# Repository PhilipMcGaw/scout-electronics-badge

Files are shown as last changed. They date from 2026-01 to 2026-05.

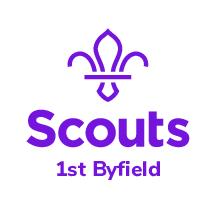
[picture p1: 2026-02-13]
KiCAD/1st Byfield.jpg

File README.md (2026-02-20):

====== Electronics badge ======

How to earn your badge:

  - Identify a number of common electronic components that are shown to you.
    - Explain, in simple terms, the functions they perform in electronic circuits.
  - Describe the systems used for marking components with their values
    - Demonstrate by identifying the values of resistors and capacitors by their markings. Explain the importance of the rating of a component.
  - Show that you know the symbols used to represent common components in circuit diagrams.
    - Show how to identify the polarity of a diode and a specific PIN on an integrated circuit.
  - Show that you’re aware of the safe working practices to be followed when handling electronic components, circuit boards and when soldering.
  - Use a multimeter to measure voltage, current and resistance in a simple circuit.
    - Explain the relationship between these values.
  - Talk about the main differences in the operation of digital and analogue circuits.
  - Construct three simple circuits.
    - One of these should be based mainly on digital electronics. They can be from a book or magazine, or you can design the circuits yourself. If possible, at least one of the circuits should be soldered using either stripboard or a custom-made printed circuit board.
  - Explain the principles behind the operation of each circuit and the typical values of voltage and current found in each.
  - Explain the possible uses of the three circuits you built.
  - Talk about the uses and benefits of electronics in everyday life.
    - Explain how electronics can be used to improve lives.

| Number  | Title                                                                                                                     | 1  | 2  | 3  | 4  | 5  | 6  | 7  | 8  | 9  | 10  |
| 1.      | Learn about resistors https://www.scouts.org.uk/activities/learn-about-resistors/                                         |    | 2  |    |    |    |    |    |    |    |     |
| 2.      | Ready https://www.scouts.org.uk/activities/ready-steady-solder/                                                           |    |    |    | 4  |    |    |    |    |    |     |
| 3.      | Multimeter multi-you https://www.scouts.org.uk/activities/multimeter-multi-you/                                           |    |    |    |    | 5  |    |    |    |    |     |
| 4.      | Thinking logically https://www.scouts.org.uk/activities/thinking-logically/                                               |    |    |    |    |    | 6  |    |    |    |     |
| 5.      | Brush bugs https://www.scouts.org.uk/activities/brush-bugs/ / https://kitronik.co.uk/blogs/resources/iet-scout-brush-bug  |    |    |    |    |    |    | 7  | 8  | 9  |     |
| 6.      | Fruit and Vegetable Power Challenge https://www.scouts.org.uk/activities/fruit-and-vegetable-power-challenge/             |    |    |    |    |    |    | 7  |    |    |     |
| 7.      | LEDs Celebrate https://www.scouts.org.uk/activities/leds-celebrate/                                                       |    |    |    |    |    |    | 7  | 8  | 9  |     |
| 8.      | Make an electric car https://www.scouts.org.uk/activities/make-an-electric-car/                                           |    |    |    |    |    |    | 7  |    |    |     |
| 9.      | Making rainbows https://www.scouts.org.uk/activities/making-rainbows/                                                     |    |    |    |    |    |    | 7  | 8  | 9  |     |
| 10.     | Power a lightbulb using potato energy https://www.scouts.org.uk/activities/power-a-lightbulb-using-potato-energy/         |    |    |    |    |    |    |    |    |    | 10  |

  * https://kitronik.co.uk/blogs/resources/scout-electronics-badge-resources
  * https://www.scouting.org/merit-badges/electronics/
  * https://cobargoscouts.org.au/jota-joti-electronics.html

  - Describe the safety precautions you must exercise when using, building, altering, or repairing electronic devices.
  - Do the following:
    - Draw a simple schematic diagram. It must show resistors, capacitors, and transistors or integrated circuits. Use the correct symbols. Label all parts.
    - Tell the purpose of each part.
  - Do the following:
    - Show the right way to solder and desolder.
    - Show how to avoid heat damage to electronic components.
    - Tell about the function of a printed circuit board. Tell what precautions should be observed when soldering printed circuit boards.
  - Do the following:
    - Discuss each of the following with your counselor:
      - How to use electronics for a control purpose.
      - Explain the basic principles of digital logic.
      - How to use electronics for three different analog applications.
    - Show how to change three decimal numbers into binary numbers and three binary numbers into decimal numbers.
    - Choose ONE of the following THREE projects. For your project, find or create a schematic diagram. To the best of your ability, explain to your counselor how the circuit you built operates.
      - A control device
      - A digital circuit
      - An analog circuit.
  - Do the following:
    - Show how to solve a simple problem involving current, voltage, and resistance using Ohm's law
    - Tell about the need for and the use of test equipment in electronics. Name three types of test equipment. Tell how they operate.
    - Demonstrate to your counsellor how to read the colored bands of a resistor to determine its resistance value.
    - Explain the differences between Through Hole and Surface Mount assembly technologies and give three advantages of each.
  - Identify three career opportunities that would use skills and knowledge in Electronics. Pick one and research the training, education, certification requirements, experience, and expenses associated with entering the field. Research the prospects for employment, starting salary, advancement opportunities and career goals associated with this career. Discuss what you learned with your counselor and whether you might be interested in this career.

  https://docs.franzininho.com.br/docs/franzininho-diy/sobre#projeto-open-hardware

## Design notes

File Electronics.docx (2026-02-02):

How to earn your badge:

1. Identify several common electronic components that are shown to you.
  a. Explain, in simple terms, the functions they perform in electronic circuits.
2. Describe the systems used for marking components with their values
  a. Demonstrate by identifying the values of resistors and capacitors by their markings. Explain the importance of the rating of a component.
3. Show that you know the symbols used to represent common components in circuit diagrams.
  a. Show how to identify the polarity of a diode and a specific PIN on an integrated circuit.
4. Show that you’re aware of the safe working practices to be followed when handling electronic components, circuit boards and when soldering.
5. Use a multimeter to measure voltage, current and resistance in a simple circuit.
  a. Explain the relationship between these values.
6. Talk about the main differences in the operation of digital and analogue circuits.
7. Construct three simple circuits.
  a. One of these should be based mainly on digital electronics. They can be from a book or magazine, or you can design the circuits yourself. If possible, at least one of the circuits should be soldered using either stripboard or a custom-made printed circuit board.
8. Explain the principles behind the operation of each circuit and the typical values of voltage and current found in each.
9. Explain the possible uses of the three circuits you built.
10. Talk about the uses and benefits of electronics in everyday life.
  a. Explain how electronics can be used to improve lives.

# History and Introduction

Electronics is the science that controls the behaviour of electrons so that some type of useful function is performed. (Electrons will be explained more fully later in this book.) Today, electronics is a fast-changing and exciting field. The rapid growth of electronics started in the early 20th century when vacuum tubes were introduced and used to manipulate electronic signals. This was something that could not be done with the telegraph and telephone circuits or the high-voltage transmitters of those days. Vacuum tubes allowed weak radio and powerful signals to be amplified, or to be made louder or stronger, and be sent on powerful waves.

Electronics changed even more dramatically in 1948 when the transistor, a small, low-powered, solid-state electronic device, was invented. Transistors are smaller than vacuum tubes, require less power to function, and are more reliable. The development of the integrated circuit, or IC, advanced this technology further. ICs can contain tens of thousands of tiny transistors built onto a small piece of conducting material. This allows for the construction and production of complex electronic circuits, which are more efficient than tubes in processing electronic signals. ICs are used in many products today, including computers, audio equipment, cell phones, appliances, and automobiles.

# How to Earn the Electronics Merit Badge

The first step in earning your Electronics merit badge is to discuss the requirements with your merit badge counsellor.

To fulfil requirement 1, learn about the precautions you should take when using, building, altering, or repairing electronic devices. Many electronic components (parts) could be damaged if mishandled. Here are some basic safety precautions; there are more safety suggestions later in this pamphlet. As you read this pamphlet and work on the requirements, pay attention to safety and see whether you can add to this list.

For requirement 2, study the chapter called “Schematic Diagrams.” You may choose a schematic diagram from this pamphlet, then copy it carefully with a pencil. Your drawing must show resistors, capacitors, and transistors or integrated circuits. Use the correct symbols for these components, label all parts, and be prepared to tell the purpose of each component. Show your drawing to your counsellor and tell what you have learned.

For requirement 3, learn how to solder and then practice soldering and desoldering wires. When you think you are ready, show your soldering skills to your counsellor. Be prepared to discuss soldering precautions, printed circuit boards, and possible heat damage to components when using a soldering iron.

Requirement 4 is demanding but fun because you will build a working electronics circuit. Choose your project carefully. Make sure that all the required parts are available at an electronics parts store, from a catalogue, or over the internet (only with your parent or guardian’s permission). Also consider what tools you will need. You can choose a project other than those in this pamphlet but check with your counselor first to make sure that the project is suitable. After you are done with the project, show it to your counselor and explain how it works.

For requirement 4 you will also learn the basic principles of digital techniques, how you can use electronics for control purposes, and about audio applications. Learn the binary system so that you know how to change decimal numbers into binary numbers and binary into decimal.

For requirement 5, you will need to solve a simple problem using Ohm’s law. You also should be able to discuss test equipment, the different types, and what they’re used for.

For the final requirement, study three career opportunities in electronics that interest you. Discuss with your counsellor the education and training needed for each.

# Tools for Electronics Work

The basic tools you will need for most of your electronics work are shown here. You can probably find some around your home and get others at an electronics parts store.

Some Basic Tools

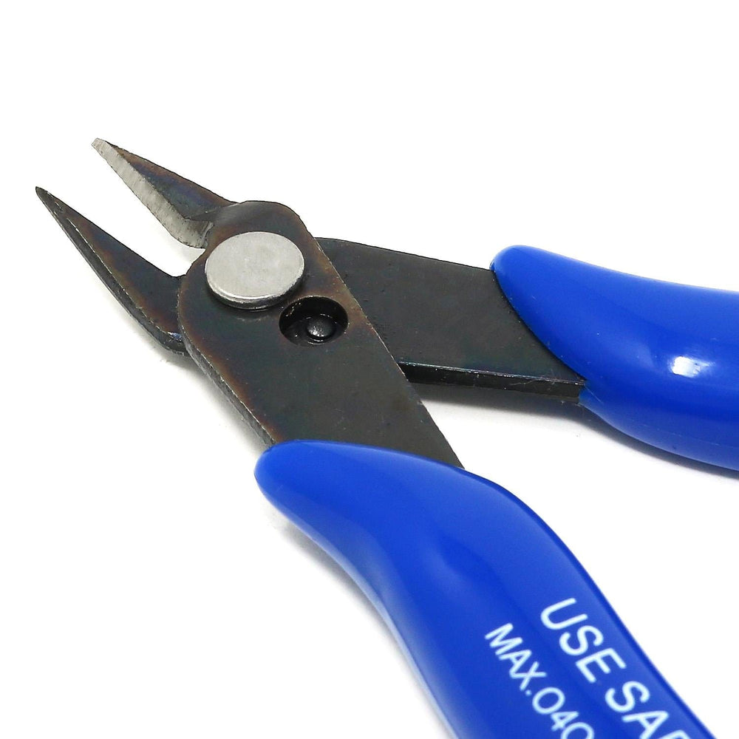
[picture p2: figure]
Precision Diagonal Cutters by The Pi Hut - The Pi Hut

https://thepihut.com/products/precision-diagonal-cutters

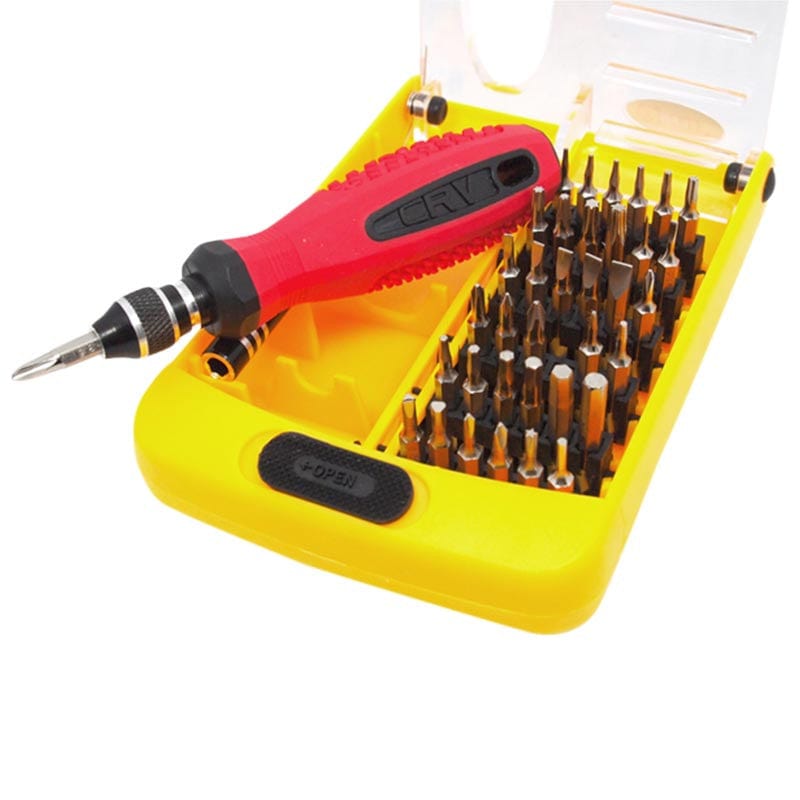
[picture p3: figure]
38 In 1 Interchangeable precise tool set by Seeed - The Pi Hut

https://thepihut.com/products/38-in-1-interchangeable-precise-tool-set

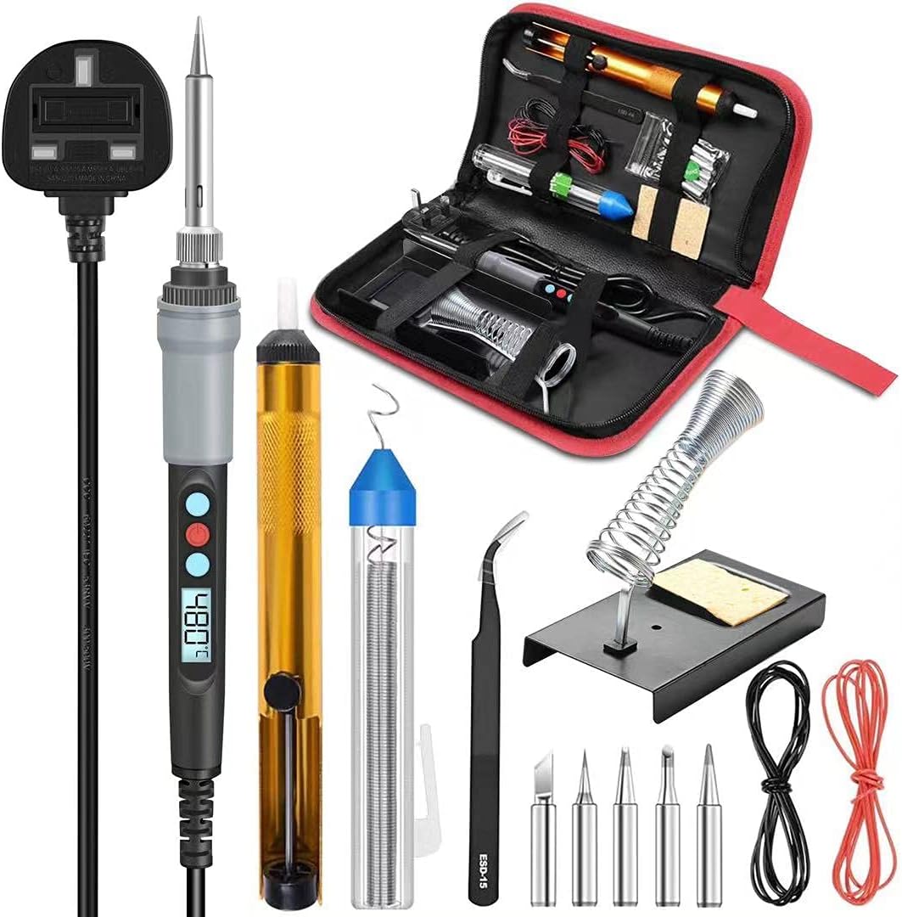
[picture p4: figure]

https://amzn.to/4a0yyuT

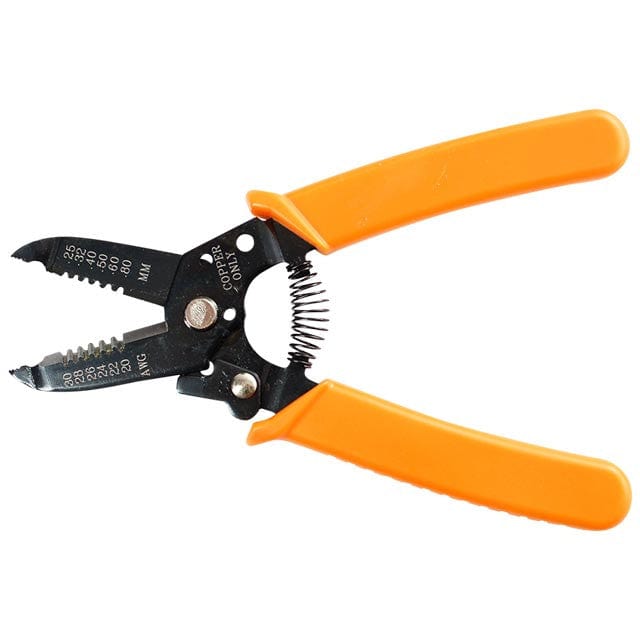
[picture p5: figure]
Multifunction Wire Strippers by The Pi Hut - The Pi Hut

https://thepihut.com/products/wire-strippers

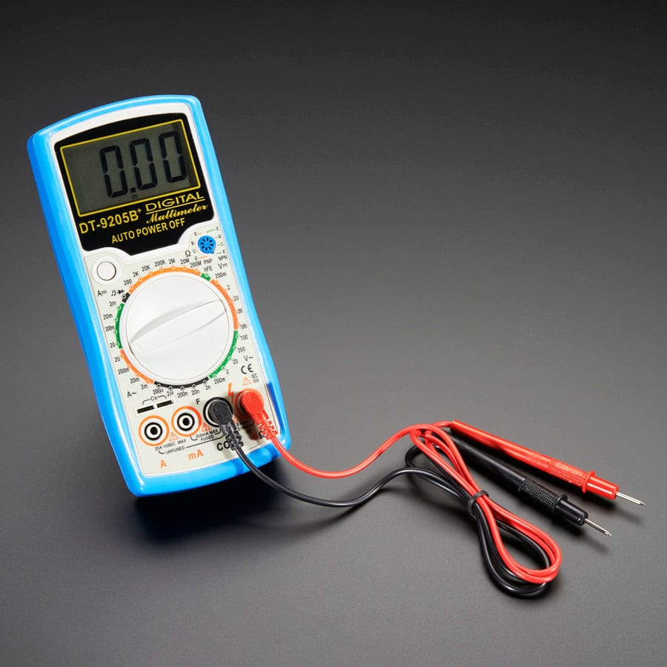
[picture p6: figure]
Digital Multimeter - Model 9205B+ by Adafruit - The Pi Hut

https://thepihut.com/products/digital-multimeter-model-9205b

For most projects, you can use any small-diameter solid or stranded hookup wire. Some projects might also require very small wire. A magnifier or magnifying work lamp is recommended for examining the circuit board to check solder connections. Most electronics parts stores have a selection of perforated circuit boards made specially for wiring electronics projects. Many come with small clips for mounting parts. These boards are ideal for building simple circuits. You also will need an electric soldering iron, which you

can buy at a hobby, electronics parts, or hardware store.

The soldering iron in a beginner’s tool kit should be a 15- to 40-watt iron with a fine chisel tip. Use a lead-free solder, like https://amzn.to/4t8N10K. Most of the solder you will need will have a diameter of 0.8 mm.

You also should have a solder wick (https://amzn.to/4bW02Ve) for desoldering a connection if you make a mistake or want to remove a component.

Use a workbench for your project if you have one. If not, you can use a kitchen table, desk, or sturdy card table. You will need to have good light and ventilation and access to power outlets. You also will need a few small boxes, trays, or jars to hold parts.

# Buying Parts

Most electronics parts stores will have the components you will need for your project. If you do a project from scratch, you will have to buy the parts separately. While you also can buy a complete project as a kit, many electronics kits found in retail stores are not soldering kits, and building a project from scratch is challenging and rewarding. Scratch projects can be inexpensive if you can scrounge for most of the parts.

However, a kit has several advantages. All the necessary assembly instructions and parts are supplied, including wire and solder. Special parts, such as printed circuit boards, come with the kit. In addition, fewer tools are required because all necessary holes are pre-drilled. Since the kit has been carefully tested, you know that the finished product will work. A complete kit generally costs less than buying the parts separately. Investigate doing a project both ways before you invest your money.

# Basic Electronics Theory

Before you learn about electronic components, let’s look at the theory behind electronics. Controlling electrons is the science of electronics. So, our study of electronics theory begins with the electron.

## Atoms and Electrons

To understand electrons, we must learn about the makeup of matter. All matter is composed of atoms, and an atom is composed of three elementary particles: electrons, protons, and neutrons. Negatively charged electrons revolve around the core (the nucleus) of the atom, which is composed of positively charged protons and neutral (not charged) neutrons.

Generally, a negatively charged electron is matched by a positively charged proton. For example, copper has 29 electrons revolving around a nucleus containing 29 protons. A basic law of nature controls electrical charges. This law simply stated is that unlike charges attract and like charges repel. This means a negative charge is drawn to a positive charge but pushes away from another negative charge. This is called electrostatic force. Normally, the positively charged protons hold the negatively charged electrons in place. However, an electron sometimes breaks away from an atom because of an outside force, such as heat, light, magnetic fields, or chemical reactions.

Once freed, electrons can “float” among atoms. These free electrons are what is important in electronics. Devices such as resistors, capacitors, inductors, and transistors are used to control the behaviour of these free electrons.

## Conductors and Insulators

Conductors act as a pathway for free electrons. Most metals are good conductors of electrons, so they can be used to “transport” electrons from one place to another. Insulators act as walls or barriers, preventing electrons from flowing where we do not want them to flow. Insulators, for example, are used on most electrical wires to protect us from electrical shock. Copper, silver, and gold are popular conductors because they have many free electrons. As an example of how to make the electrons flow, picture a length of copper wire with one end connected to the positive terminal of a battery and the other end connected to the negative terminal. The positive terminal attracts the negatively charged free electrons of the wire (remember unlike charges attract) while at the same time the negative terminal repels the electrons. The result is a flow of electrons through the wire from the negative to the positive terminal. This flow is called an electric current. An insulator works just the opposite. In some materials, such as plastics and glass, atoms hold their electrons tightly. These materials have very few free electrons. Therefore, if a length of insulator is connected to a battery the same way the copper wire was attached, no measurable current would flow.

## Current, Voltage, and Resistance

Here are some basic definitions of terms used in electronics.

- Current is the orderly movement of electrons through a conductor. Current is measured in amperes, or amps, or the rate at which electrons move past a given point. One ampere is the movement of about 6 billion billion electrons past that point in one second.
- Voltage is an electrical pressure that can cause current to flow. Voltage forces current to flow through a wire in much the same way that water pressure forces water to flow through a pipe. This electrical pressure can be caused with magnetism, chemicals, friction, light, or heat. The unit of voltage is the volt.
- The opposition to current flow is resistance. The resistance of a material is mainly determined by how many free electrons it has. If the material doesn’t have many, it will have little or no current flow. The unit of resistance is the ohm. One ohm is the amount of resistance that will allow 1 ampere of current to flow when the applied voltage is 1 volt.

## Frequency

Frequency, or cycles per second, uses the term hertz as its unit of measure. The electricity from electrical utilities is 60 Hertz AC and the voltage changes in a sine wave pattern.

## Ohm’s Law

Ohm’s law describes the basic relationships between current, voltage, and resistance. The formula for Ohm’s law is:

Voltage (volts) = Current (amperes) × Resistance (ohms)

To determine current, the formula would be:

Current (amperes) = Voltage (volts) ÷ Resistance (ohms)

If you know current and resistance, you can find out the voltage. For example, how much voltage is needed to force 2 amperes of current to flow through 10 ohms of resistance?

Ohm’s law tells us that we need to multiply our 2 amperes. (current) by the 10 ohms (resistance) to arrive at the answer: 20 volts.

If you know voltage and resistance, you can figure out current (Voltage ÷ Resistance). Therefore, how much current will flow in a circuit having 5 ohms of resistance when 15 volts are applied?

15 volts ÷ 5 ohms = 3 amperes

With these formulas, you can solve simple problems involving current, voltage, and resistance.

# Power

Another electrical quantity is power. Power is the rate at which work is done. The unit of electrical power is the watt and can be compared to the unit of mechanical power, called horsepower. One horsepower is equal to 746 watts. The formula for power is

Power (watts) = Voltage (volts) × Current (amperes)

When this formula is applied, you can determine the amount of power used by a circuit if you know the voltage and current.

For example, how much power is used by a 120-volt toaster that draws 5 amperes?

120 volts × 5 amperes = 600 watts

The power used by the toaster is 600 watts. This power is used, or dissipated, in the form of heat to toast the bread.

## Current Delivery

Electrical signals are classified as either direct current (DC) or alternating current (AC). Direct current signals are at a constant voltage or at a constant polarity where AC signals typically follow a sine wave or other pattern and alternate between positive and negative voltages. If the AC signal follows a specific pattern, the number of times the pattern repeats within one second is the signal’s frequency. The electricity from electrical utilities is 60 Hertz AC and the voltage changes in a sine wave pattern.

## Resistance and Resistors

You have learned that when you apply a voltage to the ends of a conductor, it creates a current. Its strength depends on the applied voltage and the resistance of the conductor. The resistance of a conducting material depends on three factors:

1. The kind of material
2. The length of the material
3. The diameter or thickness of the material

Temperature also is a factor in resistance. In most materials, resistance is increased when the temperature rises and decreased if the temperature is colder. In most simple circuits, however, temperature is not critical and is often ignored. The kind of material is probably the most important factor in resistance. Copper, for example, is a good conductor, while iron of a similar size has a higher resistance. Carbon has even a higher resistance than iron.

The longer the conductor, the higher the resistance will be. For instance, if the length of a copper wire is doubled, the resistance will be doubled. As an example, a 60-foot length of copper wire might have a resistance of 1 ohm. A same-sized copper wire that is 120 feet long would have a resistance of 2 ohms.

Size is important, too. A thick conductor will carry more current and offer less resistance than a thin one. Think again of water pipes. A large water pipe will allow more water to flow than a small one. When a current flows through a resistor, a component that limits or opposes the flow of a current, work is being done to move the electrons. This work produces heat and warms the resistor. Heat produced by an electric current is the basis for the operation of many electrical devices and appliances such as heaters, toasters, stoves, and soldering irons. In a lightbulb, an electrical current causes a wire filament to become so hot that it glows to produce light. Only a fraction of the power that comes from the filament produces light.

The rest generates heat, which is why incandescent bulbs are so inefficient. A resistor is designed to have a specific value of resistance, and resistors are available in a wide range of values. Standard power sizes are 1/4-watt, 1/2-watt, 1 watt, and 2 watts. These values indicate the maximum recommended power that the resistor can dissipate. The higher the power rating, the larger the resistor.

## Capacitors and Capacitance

A capacitor is a device for storing electrons, or an electrical charge, that can be released later. Imagine two sheets of aluminium foil (conducting plates) that are separated by a sheet of waxed paper (an insulator). If you connect a battery to the two aluminium sheets, electrons will flow from the sheet that is connected to the positive terminal of the battery. Simultaneously, the same number of electrons will flow from the negative terminal of the battery to the other aluminium sheet. The number of electrons that are transferred makes the voltage between the aluminium sheets exactly that of the connected battery. If the battery is removed, the aluminium sheets will remain in their charged state. If there is no leakage through the waxed paper, the sheets will remain charged indefinitely.

Any two conducting plates separated by an insulator make up a capacitor. A capacitor can consist of many conducting plates with insulating separators. Alternate plates would be connected to form interleaved stacks. The higher the voltage, the greater will be the amount of charge that is transferred from one plate to the other. The ratio of charge to voltage is defined as the capacitance of the capacitor. Or you could also say that the “electrical size” of a capacitor is its capacitance, which is the amount of electric charge it can hold. The unit of capacitance is the farad.

However, this unit is too large for most practical capacitors, so capacitors are manufactured to measure millionths of a farad (microfarads) and trillionths of a farad (picofarads, which are micro-microfarads). The insulators that separate conducting plates in a capacitor can be made of several materials, including ceramic materials, mica, certain types of paper, air, and oxide (a compound containing oxygen). A popular capacitor has been the electrolytic capacitor. In this capacitor, the insulator is an extremely thin oxide layer. The leads of electrolytic capacitors are marked positive and negative. These indicate how the capacitor must be connected for proper operation.

## Electron Tubes

The electron tube made the science of electronics possible. Although it largely has been replaced by transistors, it still has special uses. Tubes for high power are still used today in lasers, radars, strobe lights, and special-use vacuum tubes. Many high-end stereo collectors still prefer the sound of a tube amplifier over that of a transistor amplifier.

## Semiconductors

The word semiconductor is used to name a wide variety of electronic devices. Made of solid or liquid material, semi-conductors generally can conduct electricity more easily than an insulator, but not as easily as a metal. The semiconductor diode performs the same basic function as the electron-tube diode. It allows current to flow in one direction, but not the other. This diode consists of two different types of silicon crystals. An impurity (some type of substance) can be added to one area of the silicon to control the silicon’s conductivity. The silicon is said to have been “doped” when it has been treated with atoms from an impurity. These atoms combine with the silicon atoms in such a way that electrons float around freely inside the silicon. This type of silicon is called N-type (or negative-type). The N-type silicon is the cathode of the diode.

The other area of silicon also has an added impurity. But the atoms of this impurity combine with the silicon atoms in such a way that there is a shortage of one electron in the bonding. The absence of an electron is called a “hole,” and this hole can grab an electron from a neighbouring atom. Thus, a hole can “float” from atom to atom the same way an electron might. The silicon with the holes is called P-type (positive).

For current to flow through the diode, the negative terminal of the battery must connect to the N-type silicon (the cathode) and the positive terminal to the P-type silicon (the anode). The negative terminal repels the free electrons of the N-type material. The electrons are forced toward the junction where they fill the waiting holes. However, as the electrons leave the anode, new holes form. This results in a constant flow of current from cathode to anode. Current cannot flow in the opposite direction (see the illustration for the semiconductor diode). If the battery’s connection is turned around, it attracts the electrons and the holes away from the junction. Because there are no free electrons at the junction, no current can flow.

The transistor is perhaps the most important invention in the history of electronics so far. A transistor uses the P-type and N-type silicon in much the same way as a diode. However, the transistor has three electrodes, called the emitter, the base, and the collector. The collector is connected to the positive terminal of the battery, and the emitter is connected to the negative terminal. Electrons will try to flow from the emitter to the collector. However, a thin layer (the base) separates these two elements. If the base is negative, it repels the free electrons in the emitter. In this case, no current can flow from the emitter to the collector.

If the base is positive, electrons can flow into the base from the emitter. Some of the electrons will flow into the positive base lead. But because the base is very thin, most of the electrons travel through the base to the collector. Thus, if the base is made more positive, more electrons will flow. Conversely, making the base less positive will reduce the current flow. You can see then that a small voltage on the base will control the amount of current through the transistor. For this reason, the transistor can be used as an amplifier in much the same way as a vacuum tube.

Notice the symbol in the illustration used to represent the NPN transistor. Another type of transistor is called the PNP transistor. Its structure and schematic symbol are shown in the following illustration. This transistor requires opposite polarity voltages for proper operation.

NPN and PNP transistors are called bipolar transistors, and they are the most popular types used.

## Field Effect Transistor

The field effect transistor uses a single N-channel or P-channel with an insulated metal plate used to control current flow. Current enters the channel at the source lead and flows toward the drain lead at the other end of the channel. The voltage applied to the insulated plate, known as the gate, limits the current flow through the channel from source to drain. The most used FET is the metal-oxide semiconductor FET or MOSFET. An N-channel MOSFET will not conduct current if there is no voltage difference source to gate and allow current flow when a higher voltage is applied to the gate (voltage difference with respect to the source pin). A P-channel MOSFET will conduct current if there is no voltage difference source to gate and allow current flow when a lower voltage is applied to the gate (voltage difference with respect to the source pin).

Complementary MOS or CMOS technologies use one P-channel MOSFET and one N-channel MOSFET connected such that the P-channel source pin connects to the circuit higher voltage (typically power supply) and connects the N-channel source to the lower voltage supply (typically 0-volt or ground). The drain of the two MOSFETs are connected and is the circuit output. The gates are tied together. When the gates are connected to a low voltage (ground), the source to gate voltage of the N-channel is 0 volts so the channel transistor is “off” while the gate to source voltage of the P-channel FET is the “hi” voltage, so that transistor is “on” meaning the output voltage is connected to the power supply or high (for a low input). Conversely, if the two gates are tied to the higher voltage, the N-channel gate to source is now high, so it is “on” while the P-channel transistor gate to source is voltage is low, so it is “off.”

## Integrated Circuits

An integrated circuit (IC) is a complete circuit in a single package. Transistors, resistors, diodes, and capacitors can be formed in a single chip of silicon, a semiconductor. One chip can contain thousands or even millions of electronic components. Integrated circuits have revolutionized many fields, including communications, information handling, and computing. They have reduced the size of devices, while providing faster speeds and increased reliability. The individual components of ICs are extremely small and are assembled to a pattern that has been planned. A chip might look flat, but it has several layers for circuits. Switches control the electrical current through the chip. The switches manipulate the binary code (discussed below) with “on” and “off” switches. The binary code is at the core of how a computer operates.

Chips come in many different sizes, with millions of transistors being able to fit on chips the size of a postage stamp. Two basic types of IC are called linear and digital. Linear circuits include amplifiers, oscillators, regulators, and other circuits used in TV sets, audio amplifiers, radios, and hearing aids. Digital circuits include memories and arithmetic circuits and counters in watches, calculators, computers, and video games.

## Microprocessors

The microprocessor is a type of ultra-large IC. By 1971, the technique of making ICs had progressed to the point where enough computing power could be put on a single IC to form a tiny, primitive computer, or calculator. The first microprocessor was born. Today, microprocessors can incorporate more than a billion transistors, plus components such as resistors, capacitors, diodes, and wires. The microprocessor accepts input data, modifies that data in some way, and produces an appropriate output. The earliest application of the microprocessor was the calculator. A calculator accepts numbers that the user enters on a keyboard, performs a mathematical operation on those numbers that the user desires, and then sends the result to a display.

Today’s microprocessors function as the central processing unit (CPU) of computers. They also are used in many electronics systems such as cameras, printers, planes, and automobiles. The microprocessor in an automobile, for instance, examines inputs from several sensors, makes decisions based on those inputs, and adjusts such things as the mixture of air and fuel and the timing of ignition firing. The microprocessor’s most important aspect is that it can be programmed to perform an almost limitless number of applications.

## Printed Circuit Boards

A printed circuit board (PCB) consists of a sheet of some type of insulator, a composite material classified as FR-4 made of woven fiberglass cloth with an epoxy resin binder. The FR-4 material is an insulator with copper traces printed or etched onto the FR-4 surface. The copper traces are implementations of the wire lines of the schematic drawing. Parts of traces may need to be routed from one side (layer) to the other side (layer). To connect the traces, feed-through holes are added to the circuit board. Feed-through holes are drilled through the printed circuit board then filled with solder. The solder connects the copper of the top, bottom, and optional intermediate layers. Feedthrough hole’s solder is done during the fabrication of the circuit board.

Optionally, feed-through holes can be used to hold component leads. The feed through has a hole drilled through the solder for the component lead. The drilled hole is done during fabrication of the printed circuit board. The completed printed circuit board is now ready for insertion of the components drawn in the schematic.

A feed-through hole used for a component lead must be larger to allow room for the component lead diameter plus some insertion clearance of the lead into the hole. If no component lead is being inserted in the hole, the diameter of the feed-through hole can be much smaller and require less printed circuit board space. Later, during the assembly process, a component lead is inserted into the hole and the hole and lead must be soldered together to make solid electrical contact. Several layers of traces, separated by FR-4 sheets may be sandwiched together for more complex electronic designs with feed-through holes connecting the traces as needed.

## Through-Hole Technology

The technology used for placing component leads in holes drilled through the printed circuit board reached a practical limit when integrated circuits got over about 40 pins. A feed-through hole with space for the lead and the insertion tolerance meant that, based on PCB fabrication technologies at the time, integrated circuit leads needed to be about 0.100" apart. Various techniques were tried with larger IC packages including longer packages, the IC pins in a grid pattern and others. There was not a viable solution to reach what would eventually be today’s package pin counts.

## Surface-Mount Technology

By removing the component pin from going through the feed-through hole, the feed-through could be much smaller and moved away from the component. The component pins could be replaced with a square pad on the component, and the printed circuit board would have a matching pad on the “out-side” copper layer. Without the constraint of the feed-through hole with drilled lead space, component pins could be placed much closer together or more pins could be placed around the former through hole package sizes. This change led to the very high pin count packages required for today’s integrated circuits, such as the processor of your home computer.

## Schematic Diagrams

The illustrations in the previous section didn’t show you a picture of a real diode or transistor. Instead, they showed you a kind of illustrated outline, called a schematic diagram. These diagrams are a simple way of showing how electronic components are connected. In a schematic, symbols stand for the different electronic components. The schematic diagram illustrated here is for a code-practice oscillator, used to practice Morse code. The corresponding pictorial representation shows how the components look. In the schematic, a different type of symbol represents each type of component:

long and short lines represent the battery; a zigzag line stands for a resistor. In this section, you will learn these symbols so that you can understand schematic diagrams.

To start, compare the schematic diagram with the pictorial and match each symbol in the schematic with its equivalent component in the pictorial. Also match each line in the schematic with the appropriate wire in the pictorial. Notice where two lines cross in the schematic. If the wires are to be connected, a dot shows at the crossing on the schematic. If there is no dot, the two wires bypass each other and are not connected.

When you draw your schematic for requirement 2, you will need a sharp pencil, paper, and a ruler or straight edge for drawing straight lines. A compass might be helpful for drawing circles. If you have a computer with a drawing program, you might use that to draw a schematic. There are also several freely available schematic capture tools.

# Component Types

Before we look at the most common types of electronics components, as well as the schematic symbol and a pictorial of each one, let’s define and review some basic terms (also see the Basic Electronics Theory section):

- Electricity is a property that electrons have that causes them to behave in certain predictable ways.
- Electrical charge is a quantity of electricity.
- The electron is a tiny particle that has a negative electrical charge.
- Current is defined as the flow of electrons.
- Voltage is the pressure that causes current to flow.
- Resistance is the opposition to current flow.
- Direct current (DC) is current that always flows in the same direction.
- Alternating current (AC) is a current that reverses its direction of flow many times each second.
- Frequency is the number of times that a repeat its pattern in one second.

## Passive Components

### Fixed Resistor

Each resistor has a specific amount of resistance. A resistor is like a nozzle on a water hose. For a given water pressure, the nozzle controls the amount of water that is allowed out of the hose. Similarly, for a given voltage, a resistor controls the flow of electrical current.

Most resistors are made of a carbon compound. Resistors used for high currents often are made from special wire that is wound on an insulating form. The type of compound or wire used determines how much electrical current can flow for a given voltage. The value of a resistor is given in ohms. The symbol for the ohm is the Greek capital letter omega (Ω). Thus, 1Ω designates the resistance of 1 ohm. A 1kΩ resistor has a resistance of 1 kilohm, or 1,000 ohms. A 1MΩ resistor has a resistance of 1 megohm, or 1 million ohms.

The illustration below shows a variety of fixed resistors and a cross-section of a fixed resistor. The values of fixed resistors cannot be changed.

Older types of fixed resistors have bands of colour that allow you to determine their resistance value. (See “The Colour Code of Resistors” section on page 40.) The cross-section of this fixed resistor shows the inside, which is made of carbon.

Note the schematic symbol for a fixed resistor.

### Variable Resistor

The resistance of variable resistors can be adjusted. Rheostats are two-leaded devices that vary in resistance from 0 to the rated resistance value. Three leaded variable resistors, known as potentiometers (pots), have a fixed resistance between leads 1 and 3, and have a resistance on lead 2 proportional to the amount of rotation on the adjustment arm. These variable resistors can be used in appliances that need their currents adjusted or when the resistance needs to be varied, such as with lights that can be dimmed.

### Capacitor

A capacitor is a storage element for electrical charge, like a bottle that stores a liquid. The basic unit of capacitance is the farad (F). Practical capacitors have capacitance values in microfarads (µF). The physical size of a capacitor depends on its voltage rating and its capacitance value. The higher the voltage rating and the larger the capacitance value, the larger the capacitor must be.

### Inductor

An inductor is a coil of wire usually wrapped around some type of metal or hollow core material and is used to smooth out variations in the current flow. When current is applied to the coil, a magnetic field is established around the core. When the current flow stops, the magnetic field begins to collapse and in doing so induces current back into the wire until the field has collapsed. The magnetic field tends to collapse at a rate that maintains the original current in the wire. Single coil configurations are generally called a choke whereas two or more coils can be configured either as a choke to filter current changes or as a transformer for changing voltage and current values.

### Transformer

A transformer consists of two or more coils each with multiple turns of wire around the magnetic core. The primary coil is the coil where power is applied to the transformer and the other coils are referred to as secondary coil(s). The transformer uses the magnetic field established by current flow in the primary coil to induce a current in the secondary coil(s). The ratio of turns from the primary to a secondary coil determines how much the incoming voltage is multiplied on the secondary side and how much the secondary current is divided by the primary current in the secondary. Because transformers operate on changing magnetic fields caused by changing current, transformers do not operate on direct current (DC) currents.

## Semiconductor Devices

Semiconductor devices are typically made of silicon-based material. Diodes and transistors are two common semiconductor component types. Semiconductors come in various package sizes based on the amount of power they must dissipate in rated operation.

### Diodes

Diodes operate as check valves, passing current in one direction but not the other. A diode’s most common application is in power supplies. It changes alternating current (AC) into direct current (DC).

### Transistors

Transistors are solid-state devices used for controlling current. A very small input current controls a much larger output current. For example, the small current from a microphone can control a much larger current that drives a loudspeaker. This is the idea behind the audio amplifiers used in public address systems.

### Integrated Circuits (ICs)

Complex circuits are available in integrated circuit (IC) form at inexpensive prices. The IC, which typically consumes little power, is reliable, cheap, and small. Because devices using ICs can be improved and made cheaper, the IC has replaced traditional components in many applications. As shown here, ICs come in several types of packages. The dual in-line package (DIP) is the most popular style for most hobby applications.

Schematic symbols for ICs are typically very function specific.

## Electromechanical Components

### Microphone:

A microphone changes sounds into electrical impulses. Either a thin, flexible disk (a diaphragm) or a crystal in the mike vibrates whenever sound strikes it. The vibrations are changed into small electrical signals. These signals typically need to be amplified before they are usable.

### Speaker

A speaker then converts the electrical impulses back into sounds. An electromagnet moves a speaker cone based on the incoming audio signal. The speaker cone moves the air around and it which causes the audio sound to spread across the space and recreating the original sound.

### Switches

Switches are an important part of almost all electronic equipment. They come in a wide variety of shapes, sizes, and functions. Switches are categorized by the number of circuits they switch (single, double, triple, etc.) and then by the number of switch position contacts. A switch may have an output contact for each position of the switch. The switch will typically have a default position. A circuit that makes contact in that position is called a Normally Closed (NC) contact or in drawing below from terminal A to C. If the switch is moved out of default position, and contacts an electrical terminal, that position is called Normally Open (NO) and is shown as connections A to B in drawings below).

The simplest is the single-pole, single-throw type. When closed, this switch completes a circuit, allowing an electric current to flow. When it is open, the circuit is broken, and the current does not flow. The on-off switches on most electronic devices are of this type (above left).

A single-pole, double-throw switch has a contact arm that can be set in either of two positions. In the example shown here, terminal A can be connected to either terminal B or terminal C. The dashed line between the switches shows the mechanical connection (above centre).

A double-pole, double-throw switch can simultaneously switch two wires from one circuit to another. It can be thought of as two single-pole, double-throw switches that operate together (above right).

A rotary or selector switch has one or more arms (poles) that can be set to various positions. A single pole 10-position switch is shown below. Notice that the terminal at the very bottom connects the signal to the rotatable arm.

### Relays

A relay is a magnetically operated switch. It has a wire coil wrapped around an iron core forming an electromagnet. When current flows through the coil, a magnetic field develops. The magnetic field attracts a movable part called an armature, which moves all relay switch poles from normally Closed (magnet off) to Normally Open (magnet energized).

A relatively small current can cause the switch contacts to close, but the contacts can handle a much heavier current. The relay allows a small current to switch higher current(s) on or off. By using several contact sets (single, double, triple or more poles and single or double throw). A multi-pole relay allows a single control (coil) current to control several different currents simultaneously.

## Chemical Components

### Batteries

Batteries are made from several types of materials for different uses. Alkaline, lithium, and mercury batteries are used when long life is desired. Nickel-cadmium batteries give shorter service but can be recharged. The nickel–metal hydride battery is replacing the nickel-cadmium battery because it doesn’t suffer the memory effect (that is, not allowing a partially charged battery to fully recharge before use). Lithium-Ion type batteries have replaced many of the older battery types. Zinc-carbon also is used in many inexpensive dry-cell batteries. Most electronic circuits and products operate at low supply voltages and have low power requirements. These devices are often driven from small batteries or DC voltage sources. Depending on the type of product, a coin battery, one, two or four flashlight batteries are often adequate for relatively long service.

Ordinary flashlight dry cells produce approximately 1.5 volts. Four 1.5-volt cells connected in a series can provide 6 volts. Single 9-volt batteries also are used.

### Photocells

A photoelectrical cell changes one or more of its characteristics when exposed to light. It is popularly called the electric eye, which controls operations such as traffic lights, door openers, and devices that activate lights at dusk and turn them off at dawn. One type of photoelectric cell is called a photoconductive cell. Another name for this type of cell is the light-dependent resistor (LDR). This special resistor has a small window so that light can strike the resistance material. Generally, such a cell has a high resistance when in darkness. Another type is called a photovoltaic cell. This is the familiar “solar cell” that is used to power electronic equipment on spacecraft. It produces a low voltage across its terminals when exposed to light, especially sunlight, thus converting light energy into electrical energy.

## Other Component Types

There are many other types of components used in electronics, but these are the more common components that a hobbyist is likely to use.

# The Colour Code of Resistors

The value of a resistor is specified in ohms and is indicated by coloured bands around one end of the resistor. The electronics industry devised this system because small, printed numbers would be too hard to read or might be concealed by the position of the resistor.

Most resistors have four bands, with the first three (counting from the end of the resistor) indicating the value in ohms. The fourth, which is either silver or gold, indicates the tolerance (discussed below). colours used for the bands are used in place of numbers. To determine the resistance value in ohms, examine the colour bands starting with the one closest to the end of the resistor.

Suppose a resistor has a brown, a black, and then a brown band. The code chart shown here tells you that brown represents the number 1. The second black band represents the number 0. The third band tells you how many zeroes to add to the first two numbers. In the example, the band is brown, so you add one zero. Therefore, the value of this resistor is 1-0-0, or 100 ohms.

Now try the example for the resistor shown here, which has a red band first, then a yellow band, and then an orange band. The red band means that the first number is 2. The yellow band corresponds to the number 4. The orange band tells us to add three zeroes. Thus, the value is 2-4-000, which translates to 24,000 ohms, or 24 kilohms (kΩ).

Most surface mount components are too small for colour bands, so the colour bands are converted back to digits and printed onto the top of the resistor as 243 for 24,000 ohms, or 24 kilohms (kΩ).

# Soldering

Before you begin working with a circuit, read and study this chapter on soldering. Anyone working in electronics must know how to solder well, and safely. It takes practice, but once you learn, you will be able to properly assemble an electronics project. In all electronics work, the wiring connections must be secure. A loose connection in a radio, for example, could result in noise, scratching sounds, or no sounds at all. Poor connections in a TV could disrupt the sound and picture. And beyond just a radio and a TV in someone’s home, the safe operation of airplanes and the lives of astronauts in flight depend on secure electronics connections.

Soldering is not just gluing metals together like you glue together pieces of wood. Done correctly, soldering unites the metals so that electrically they act as one piece of metal. You do this with a mixture of lead and tin solder and a soldering iron.

## The Soldering Iron

An inexpensive pencil-type soldering iron of no more than 40-watt capacity (15 to 25 watts are also suitable) is the best for electronics work. The tip should be 1 to 2 mm; the solder should be 1 mm. It is helpful to get an iron with interchangeable tips of different diameters or shapes to be used on different kinds of work. The iron should be well-balanced and have a handle that will remain cool while you work. Tinning your iron means coating the tip of the solder iron with a thin coat of solder. If your iron is new, read the instructions about preparing it for use. Most new irons are already tinned, so you might not have to tin it. If the tips are silvery, you can use them as they are. If instructions aren’t included with your iron and the tip is not silvery, first use a fine file to file the tip until it is shiny. Then heat the iron and coat the tip with rosin-core solder. Be sure to coat all sides of the tip.

If you have an older iron that has been used and the point is already silvery, just wipe it clean with a cloth, and you are ready for work. If it is dull or looks coppery, file and tin it. You also should have a heat-resistant bench-type iron holder so that the hot iron can safely be set down between uses. Look for one that has a holder for tip-cleaning sponges.

## How to Solder

A well-soldered joint, one that will be reliable in use, will be nice and shiny looking. To achieve a well-soldered joint, make sure you do the following:

1. Solder with a clean, well-tinned tip. Wipe the tip on a damp sponge before soldering and between soldering.
2. Make sure all wires, parts, and the circuit board to be soldered are clean.
3. Make a good mechanical joint before soldering.
4. Allow the joint to get hot enough before applying solder, then apply an adequate amount of solder to the joint. Only heat the joint with the solder iron, not the solder itself. When you touch the solder to the joint, the solder will flow onto the joint
5. Allow the solder to set before handling or moving soldered parts.

Remember that in preparing work for soldering, dirt is the enemy of soldering. A solder will not take if parts are dirty, so be sure to completely clean all wires and surfaces before applying solder. Use fine sandpaper or emery paper to clean flat surfaces or wire. If you do have dirty parts or a dirty surface, you might try to use too much heat to force a connection. When preparing wires, remove the insulation with wire strippers or a hobby knife. If using a knife, hold the knife at an angle as if you were sharpening a pencil. Do not cut straight into the insulation because you could nick the wire and weaken it. For enamelled wire, use the back of the knife blade to scrape the wire until it is clean and bright.

Next, tin the clean end of the wire. Hold the heated tip of the soldering iron against the undersurface of the wire and place the end of the rosin-core solder against the upper surface. As the solder melts, it will flow on to the clean end of the wire. Hold the hot tip of the iron against the under surface of the tinned wire and remove the excess solder by letting it flow down the tip. When properly tinned, the exposed surface of the wire should be covered with a thin, even coating of solder.

Unless you are creating a temporary joint, the next step is to make a good mechanical connection between the parts to be soldered. For instance, wrap the wire carefully and tightly around a soldering terminal or soldering lug. (Bend wire and make connections using long-nosed pliers.) When connecting two wires, make a tight splice before soldering. Once you have made a good mechanical contact, you are ready to solder.

When you are working with an ordinary circuit board, you will bend the wires of a component through the board. For those parts, such as some resistors, that become hot when in operation, raise them slightly above the board to allow some air circulation. The next step is to apply the soldering iron and solder to the connection. The temperature of all the parts that are being soldered should be raised to about the same degree before applying the solder. If soldering a spliced wire, hold the iron below the splice and apply solder to the top of the splice. If the tip of the iron has a bit of melted solder on the side held against the splice, heat is transferred more readily to the splice, and the soldering can be done more easily. Don’t try to solder by applying solder to the joint and then pressing down on it with the iron.

It usually takes two to three seconds to solder on a printed circuit board. Remember: Too much solder on a joint might cause short circuits with adjacent joints. However, if you don’t apply enough solder, you might not form a secure and fully working joint. When soldering the wires of a component, you might snip the extra wire leads off before soldering. However, with some components, such as semiconductors, it might be best to snip the surplus wire after you have made the joint.

Don’t disturb the soldered joint until the solder has set. This might take several seconds, depending on the amount of solder used to make the joint Then take a good look at the joint. It should have a shiny, smooth appearance. It should not be pitted or grainy. If it is, then reheat the joint, scrape off the solder, clean the connection and start over.

After the solder is well set, pull slightly on the wire to see whether it is a good, tight connection.

## How to Desolder

In case you accidentally make a wrong connection or must move a component that has been placed incorrectly, you should learn how to desolder connections. Take care when desoldering to avoid breaking or destroying good parts. The leads on components such as resistors or transistors and the lugs on other parts might sometimes break off when desoldering a good, tight joint. To avoid heat damage, use as much care in desoldering delicate parts as you do in soldering them.

There are two ways to desolder. The first and usually easiest way is to use a metal wick or braid on a small dispenser reel to remove the melted solder. This braid is available at most electronics parts’ stores. Place the braid against the joint that you want to desolder. Use your heated soldering iron to gently press the braid against the joint. As the solder melts, it is pulled into the braid. Don’t let the joint cool while the braid is resting against the joint. By repeating this process, you can remove virtually all the solder from the joint. Then reheat the joint and lift off the component leads.

The second method involves using a desoldering pump, or a vacuum device, to suck up the molten solder. Most electronics parts stores have these devices. Follow the manufacturer’s instructions for the pump you are using, but here are some general guidelines. Use your soldering iron to heat the joint you want to desolder until the solder melts.

Then push down on the top of the pump to remove the air inside. Next, quickly place the tip of the pump on the melted solder you want to remove and press the button on the side. This will cause the pump’s plunger to rise rapidly and create a vacuum inside. The rush of air at the tip of the pump will pull the melted solder in. Repeat until you have removed most of the molten solder. Then reheat the joint and gently pry off the wires. Experiment with and practice your soldering techniques to fulfill requirement 3 before you begin working on your circuit. Use pieces of wire or some old components and wire. Practice until you can solder joints that are smooth, shiny, and tight. Then practice desoldering some of the connections until you are satisfied that you can do them quickly and without breaking wires or lugs.

## Soldering Printed Circuit Boards

Most electronic devices use one or more printed circuit (PC) boards. A PC board is made of a nonconducting material, such as a thin sheet of fiberglass or phenolic resin (plastic) that has a pattern of foil conductors “printed” on it and has predrilled holes designed to hold components. You insert component leads into the holes and solder the leads to the foil pattern. This method of assembly is widely used, and you probably will use it if you choose to work with an electronics kit. Printed circuit boards make assembly easier. First, insert component leads through the correct holes in the board. Mount the parts tightly against the circuit board unless otherwise directed. Insert a lead and then bend it slightly outward to hold the part in place. Then follow these steps.

1. Touch the tip of your soldering iron to both the component lead and the foil until they are uniformly hot enough to melt the solder.
2. Apply a small amount of solder to both the tip and the connection.
3. Remove the iron and let the solder set before moving the wire or the board. The finished connection, as you have learned, should be smooth and shiny.
4. Finally, clip off the excess wire length.

Occasionally a solder “bridge” will form when solder connects between two adjacent foil conductors. You must remove such bridges, or a short circuit will exist between the two conductors, and the circuit won’t function properly. Remove the bridge by heating it with your soldering iron and quickly wiping away the melted solder with a soft cloth.

# Control Devices

An important application of electronics is the control of certain operations with the use of control devices. For example, control devices can make lights go on at certain times or open doors automatically. To satisfy requirement 4, you will build a working electronic circuit. You may choose to build a control device.

## Building a Control Device from Scratch

You can build a control project from a kit, but you may want to build a project from scratch. The one shown is easy to build and fun to use. It is a control circuit that uses light to control an audible alarm. This is a popular type of control circuit. It could be used to detect when the sun is shining so you can turn out your lights and save power.

The circuit is constructed on the single piece of 3-by-4-inch perforated board. While the exact size is not critical, a board that is too big is better than one that is too small. The holes in the board need to be 1/10 inch apart. This is necessary so that the pins of the op amp will fit.

Many types of boards are available. The board used (and shown in the photographs) for this project has foil patterns designed especially for integrated circuits, which makes the project easier. To use this type of board, insert components through the board from the top and solder to the foil patterns on the bottom of the board. You make connections from one component to the next by using short wires called jumpers.

## Procedure

To build this circuit, follow these steps.

Step 1—Gather the parts. You may be able to buy parts at an electronics supply store, but more easily today you can purchase electronic components online (see the resources section at the back of this book). It’s a good idea to make sure you can find all the parts before you buy any of them. This circuit will work with a wide variety of parts.

Step 2—Lay out the circuit board. Before you begin, decide where each component will go on the board. The illustration here shows a suggested layout. Lay the components on the board and trace the outline of each to make sure everything will fit properly.

Step 3—Drill the holes. You must drill several holes (see the illustration for the pattern) in the circuit board before mounting any components. The four holes at the outer corners are for the four standoffs, or legs, that will hold the circuit board. It is recommended that you buy a board that has these four holes already drilled. This will leave you with only three holes to drill. The first is the small hole for the battery holder. Make this hole slightly larger than the screw that holds the battery holder to the board. Two larger holes are required for the potentiometer and the switch. In each case, make the hole slightly larger than the part that is to be inserted through it. Drill the holes carefully so you don’t damage the perforated board.

Step 4—Mount the IC. Attach the 741 op-amp first. It must be mounted so that its pins are attached to foil patterns that allow additional components to be attached. Insert the IC in the top of the board.

Identify pin 1 of the 741 Op amp IC as illustrated on the top of the next page. Mark pin 1 on the board with a pencil so that it is easier to identify each of the pins as you solder components to them.

Step 5—Mount the LDR. Insert the leads of the light-dependent resistor into the board at the location shown and solder the leads to the foil. Don’t worry about which lead is which. The LDR can be turned either way.

Step 6—Mount R2, R3, and R4. Insert the leads of the resistors at the locations shown. Bend the leads over so that you can insert them through the board and solder them to the bottom side. Don’t worry about which lead is which. The resistors can be turned either way.

Step 7—Mount the transistor.

Insert the transistor (Q1) into the board, carefully observing the emitter, base, and collector connections. The drawing illustrating the 2N3053 transistor seen at the bottom of the page shows how to identify the three elements.

Step 8—Mount the buzzer. Insert the buzzer (PB) through the board. Note that the minus (–) and plus (+) sides must be connected as shown in the schematic.

Step 9—Mount the switch. First remove the retaining nut. Mount the switch by pushing it through from the bottom of the board. Attach it to the board with the retaining nut. Cut two lengths of wire, each about 3 inches long. Remove 1/4 inch of the insulation from each end of the wire. Turn the board upside down and connect the centre switch post to a foil pattern using a prepared wire and one of the side of the switch posts to another foil pattern using the other wire.

Step 10—Mount the potentiometer. Remove the retaining nut. Mount the potentiometer (R1) by pushing it through from the bottom of the board. Attach it to the board with the retaining nut. Cut three lengths of wire, each about 3 inches long. Remove 1/4 inch of insulation from each end of the wire. Turn the board upside down and connect the potentiometer lugs to the foil patterns by using the three prepared wires as seen in the top view shown here.

Step 11—Mount the battery holder.

Step 12—Mount the battery clip. Strip 1/4 inch of insulation from the ends of the battery clip’s black and red leads. Solder the black and red leads to the board. Do not connect the battery yet.

Step 13—Interconnect each of the components using small jumper wires, being sure each wire is electrically connected between the correct components. A good way to do this is to refer to the schematic and colour each line on the schematic as you connect that jumper wire on the board. Cut each wire to the length needed and remove 1/4 inch of insulation from each end of the wire. Insert the jumper from the top of the board and solder to the foil on the bottom.

Step 14—Check all wiring. Before you apply power, recheck all wiring as described in the soldering section. Make certain that all components are interconnected properly. Check the pins of the op amp to make certain that you have the pin numbers right. Also recheck the placement of the transistor (Q1).

Step 15—Apply power. Attach the battery clip to the battery. If the buzzer sounds, flip the on-off switch to the opposite position. Place the battery in the holder.

Step 16—Coarse-adjust R1. Flip the on-off switch to the “on” position. If the buzzer does not sound, adjust the potentiometer until you hear a sound from the buzzer. If you cannot make the buzzer sound by turning the potentiometer, flip the switch in the “off” position and adjust the potentiometer until the buzzer sounds. If the buzzer will not sound in either switch position, then immediately disconnect the battery and recheck all wiring. Correct the problem by rewiring as necessary. Repeat the process until you hear a tone from the buzzer.

Step 17—Fine-adjust R1. Once you get a sound from the buzzer, cover the LDR with a finger to block light from the device. With the LDR covered, back off the setting of the potentiometer just to the point where the buzzer no longer sounds. The buzzer should now sound when the LDR is uncovered but stop buzzing when the LDR is covered. The circuit is detecting the presence of light and responding by sounding the buzzer.

## Circuit Operation

To understand how the circuit works, refer to the schematic diagram shown on the previous page. Start at the buzzer (PB) and work backward. The buzzer will sound when current flows through it. Transistor Q1 controls the current through the buzzer. When Q1 conducts, current flows through Q1 and the buzzer, creating the sound. In turn, the 741 op amp controls Q1. The 741 (IC1) is an integrated circuit that contains dozens of transistors connected as a very high-gain amplifier. This means that it can amplify extremely tiny differences in the voltages applied to the two input terminals (pins 2 and 3).

The resistance of the light-dependent resistor (LDR) determines the voltage on pin 3 of the op amp. If no light strikes the LDR, the resistance across the LDR is high, which causes the voltage at pin 3 of the op amp to be low. When light hits the LDR, its resistance falls and the voltage on pin 3 of the op amp increases.

Before using the circuit, in steps 16 and 17, you adjusted the setting of R1. Moving the arm of R1 changes the voltage at pin 2 of the op amp. With the LDR shielded from light, you set R1 just below the point at which the buzzer is activated. When R1 is properly set, the voltage at pin 3 is slightly lower than the voltage at pin 2. The op amp amplifies this tiny difference in voltage and produces a very low voltage at its output. This low output voltage holds Q1 cut off so that no current can flow through the buzzer.

When light hits the LDR, as was noted, its resistance drops. This increases the voltage at pin 3 of the op amp. The op amp amplifies this difference, producing a high voltage at its output. This turns Q1 on, forcing current through the buzzer and sounding the alarm.

# Digital Electronics

Since the use of transistors began in 1948, the field of electronics has undergone a revolution that continues to allow for the introduction of a vast array of new devices. The development of digital electronic components has revolutionized fields such as computing, communications, and information handling. Such components have replaced many traditional circuits and components.

Possibly the best example of this revolution is the personal computer and related products. Other examples are digital watches, digital thermometers, hand-held computers and games, complex calculators, electronic games, televisions, and digitally recorded music and videos.

## Binary Number System

To understand digital electronics, you must first learn the binary number system, which is used in digital equipment.

The decimal system of numbering uses 10 different digits: 0, 1, 2, 3, 4, 5, 6, 7, 8, and 9. This number system is suitable for people but is too complex to be used by electronic circuits. Digital logic is a simple process that can make only two decisions: true or false. So, the binary number system has only two digits: 0 and 1. Thus, “true” can be presented by 1 and “false” by 0.

With only two digits, how are numbers larger than 1 represented? The answer is the same way numbers greater than 9 are represented in the decimal system. In the decimal system, the highest single-digit number is 9. We represent numbers greater than this by using two or more digits in combination. That is, 10 is represented by using the digits 1 and 0 together.

In the binary system, the highest single-digit number is 1. To represent numbers greater than this, we again use two or more digits in combination. The number 2 cannot be represented by the symbol “2” because this digit is not used in the binary system. Instead, the digits 1 and 0 must be used together, to form 10. Therefore, in the binary system, 10 represents the number 2 and not the number “ten.” The number 3 is represented by the next larger two-digit number of 11.

Now, how do we represent the number 4 in binary? Since we no longer have two-digit possibilities, we must use a three-digit number. The lowest three-digit number is 100. In the decimal system, this means “one hundred.” In the binary system, 100 means “four.”

Here is a chart showing decimal numbers up to 17 and how to represent them using the binary system. Study this table to help you understand the binary sequence. Then try to continue the list to 32 (decimal), or 100000 (binary).

Charly Plexing

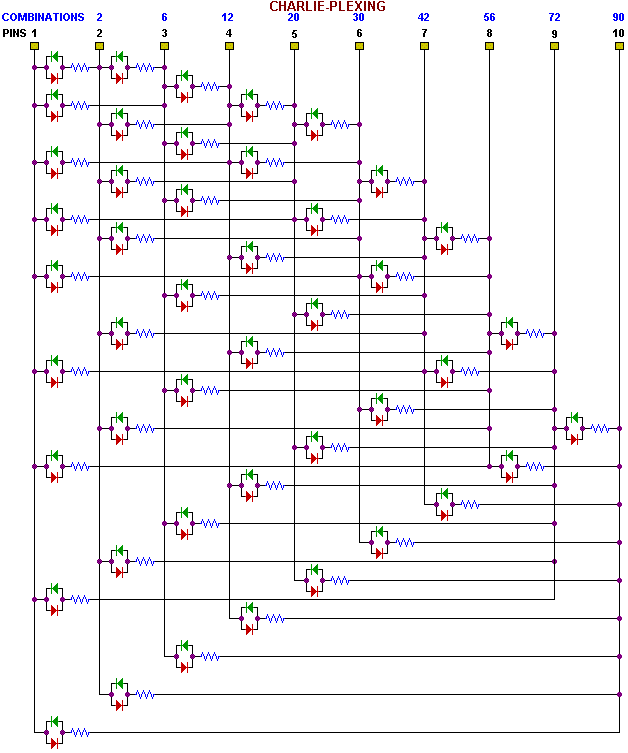
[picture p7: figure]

# Woggle

This is derived from the Scouts Queensland eWoggle, and follows the design principles laid out in the document “Circuit design principles for Scout electronics projects for JOTA/JOTI“ by Michael Gross of Cobargo Venturers (https://cobargoscouts.org.au/jota-joti-electronics.html), I have also combined the functionality of the eWoggle with the Franzininho DIY (https://docs.franzininho.com.br/docs/franzininho-diy/sobre) Arduino like capabilities allowing the scouts to upload new firmware after they have assembled their woggles.

## Woggle KiCad files

The woggle was designed in KiCad,

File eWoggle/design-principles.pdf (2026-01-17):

# Circuit design principles for Scout electronics projects for JOTA/JOTI

## Aim

- To make simple circuits from discrete components and single function integrated circuits, so that Scouts can learn that the circuits are just composed of simple building blocks that can be easily understood.
- Design circuits that are both useful and appealing to the youth members
- Circuits must be able to withstand the assembly, and subsequent handling. (it must be tough)

## Issues

- Soldering and assembly Skills of youth members learning to solder can be rather “harsh” on PCB’s. 10-20% failure is not uncommon.
- Some components can be fragile. (physical weakness and static issues)
- Commercially available kits tend to have the battery, Speaker, switches and other components separate from the PCB - the end result is that the leads tend to be broken off speakers and batteries easily.

## PCB Design principles

1. All components must be mounted on 1 board - e.g speaker, battery etc.
2. Use only most commonly available components
3. Special components that have limited availability, must have different options available, and the board must be designed to accept a number of alternatives if these are not available.
4. Circuits should use as little power as possible to extend battery life.

## PCB Design

1. IC’s - all mounted on sockets - iC’s only inserted after soldering is checked, also ensures that IC’s are not damaged though too much heat or static.
2. Battery holders - PCB mounted, but also attached by double sided tape to take the strain off the pins. Must be able to take different pin spacing from different manufacturers. Also be able to take a battery holder with wires (separate holes for this if necessary)
3. Speakers - PCB mount preferable - encased with pins, or bare speaker with leads. provision must be made to take different size speakers with different mountings. Attachment, solder in, or stick on (small mylar speakers tend to have a protruding ring that makes it easy to stick them on), also provision for screw holes, or even cable tie attachment.
4. On/Off Switches - preferable to Scouts just removing the battery. Switches must be anchored to the board by their casing as well as their leads if possible. Cases must be 1 piece, not spot welded together, so they do not break apart. Switch toggle must not extend past the board boundary, so there is less risk of it breaking off.
Michael Gross - Cobargo Venturers | V1, 11th July 2020 | Page - 1

Momentary switches are preferable, so that circuits do not accidentally get left on and drain the battery. If Momentary switches are not suitable, then a power on led should be used as indication that the power has not been turned off.

5. Silk Screen - Front of PCB - component labelling, orientation “+ and -“, component outline, all special solder pads labelled - eg battery pcb mount, battery wire mount.
6. Silk Screen - Back of PCB - Large white space for Scouts name and group name. Revision number, circuit name
7. Lanyard attachment hole (5mm) - at the top of the board
8. Larger solder pads (2.5 to 3mm) - to better handle heat dissipation from excessive solder and extended heating times, and make it easier to solder.
9. Wider tracks (min 0.75mm) - in case pads are delaminated (common), so that component leads can be bent over solder mask scraped away and lead soldered to the remaining track - saves replacing the whole board and starting again.
10. Track Layout - last section of track to plated through holes is always on the solder side so that if a component completely covers the holes (eg pcb mount speaker or battery holder), and the pad is delaminated, the pin can still be connected to the track (see step 9).
11. Pin spacing - leave enough space between component ends and through holes so that the leads are not bent close to the component, this also allows for different value components - eg ½w if ¼ w resistors are not available
12. Room for components - ensure that all components have enough room around them to make assembly easy.
13. Axial leads components where possible as there is more spacing between pins on the board - so less likelihood of bridging holes.
14. Switches - connect all pins if they have connection to other pins, so if a track is delaminated then the switch will still work.
15. Only one track to pad connection, so that if a pad is delaminated then only one join has to be made
Michael Gross - Cobargo Venturers | V1, 11th July 2020 | Page - 2

If the middle pad is delaminated then you need to make 2 connections - not preferable

If the middle pad is delaminated then you need to make only 1 connection - much easier to fix.

Layout summary

Pad sizes
1. Oversize pads - set to min 3 mm round on axial components
2. if pads close together then 2.5mm* 3 mm oval or round shape
3. Ic pads 2.5mm x 1.5mm oval

Track sizes and layout
1. 0.75mm tracks - to handle heat dissipation better, and allow for easy lead connection if pad is delaminated
2. Move tracks as far away from other holes as possible
3. Last section of track to through hole to be on component side.
4. 1 track to 1 pad, T join tracks instead, so that if a pad is delaminated there is only 1 connection to make.

Customisable Screen print suggestions
1. Scouts State Logo
2. Region Logo - if available)
3. Scout Group - name
4. Group website URL
5. Event details - JOTA/Jamborette and year if applicable
6. On Back - large white space for Name and also for Group/section

Contact - Venturers@cobargoscouts.org.au

Michael Gross - Cobargo Venturers | V1, 11th July 2020 | Page - 3

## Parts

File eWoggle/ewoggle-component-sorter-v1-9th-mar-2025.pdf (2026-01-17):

# eWoggle Component Sorting sheet and installation order

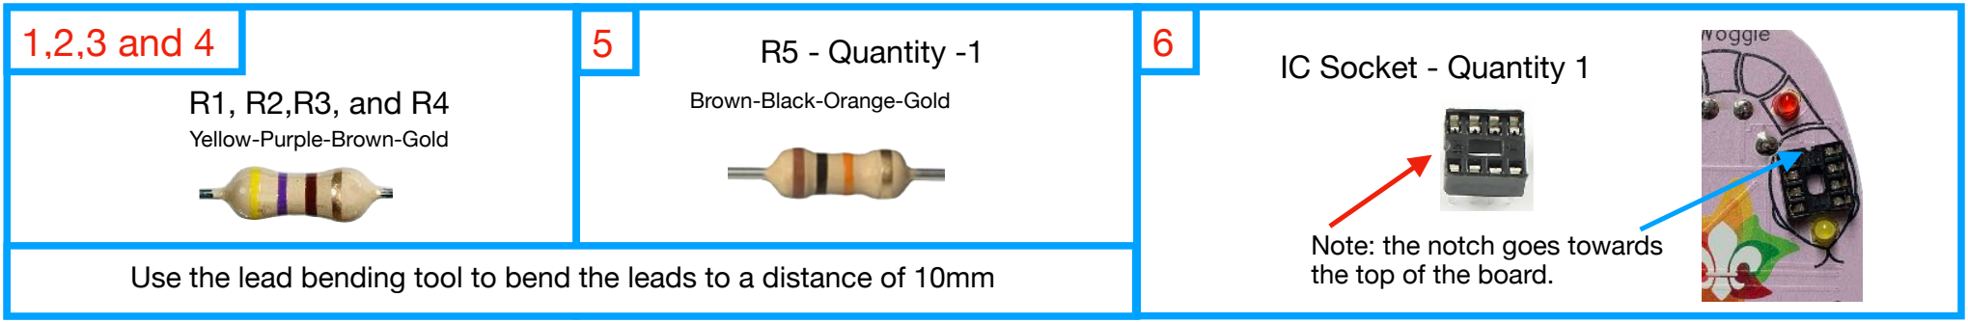
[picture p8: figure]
R1, R2,R3, and R4; Yellow-Purple-Brown-Gold; R5 - Quantity -1; Brown-Black-Orange-Gold; 1,2,3 and 4; Note: the notch goes towards the top of the board.; IC Socket - Quantity 1
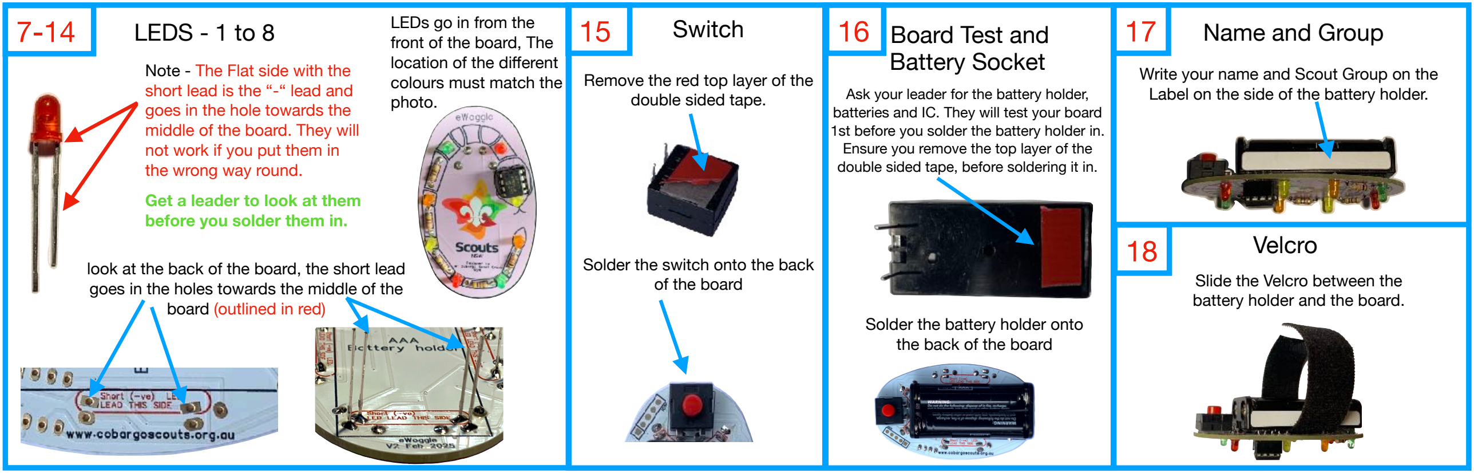
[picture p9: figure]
LEDS - 1 to 8; Write your name and Scout Group on the; Switch; Remove the red top layer of the double sided tape.; Board Test and Battery Socket; Ask your leader for the battery holder,; Ensure you remove the top layer of the; Note - The Flat side with the short lead is the “-“ lead and goes in the hole towards the middle of the board. They will not work if you put them in the wrong way round.; Get a leader to look at them before you solder them in.; Velcro 18; Name and Group; board (outlined in red); Solder the switch onto the back of the board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

1st Cobargo Scouts | www.cobargoscouts.org.au | V1 - Mar 2025

Do not take this sheet,

## please leave it on the table

Label on the side of the battery holder. batteries and IC. They will test your board 1st before you solder the battery holder in.

double sided tape, before soldering it in.

## Use the lead bending tool to bend the leads to a distance of 10mm

## Red numbers represent the order in which the components

should be installed.

look at the back of the board, the short lead goes in the holes towards the middle of the

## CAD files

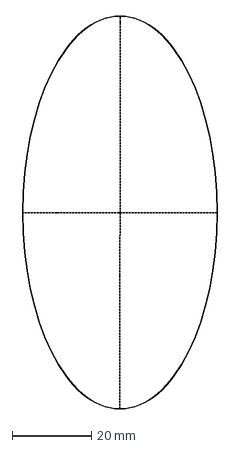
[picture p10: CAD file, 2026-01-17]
KiCAD/PCB Outline.dxf
49.0 x 99.0 mm

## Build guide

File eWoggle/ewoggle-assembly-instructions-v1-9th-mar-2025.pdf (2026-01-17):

# eWoggle assembly instructions

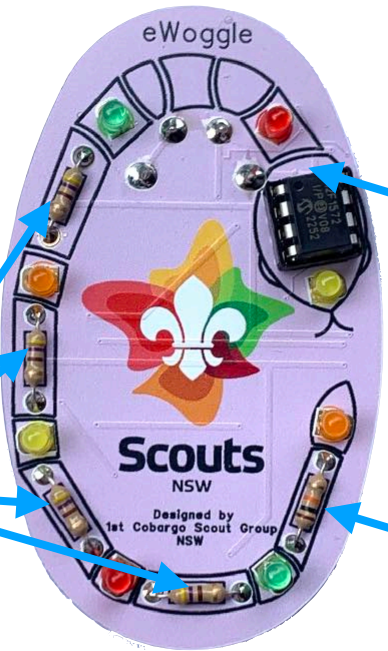
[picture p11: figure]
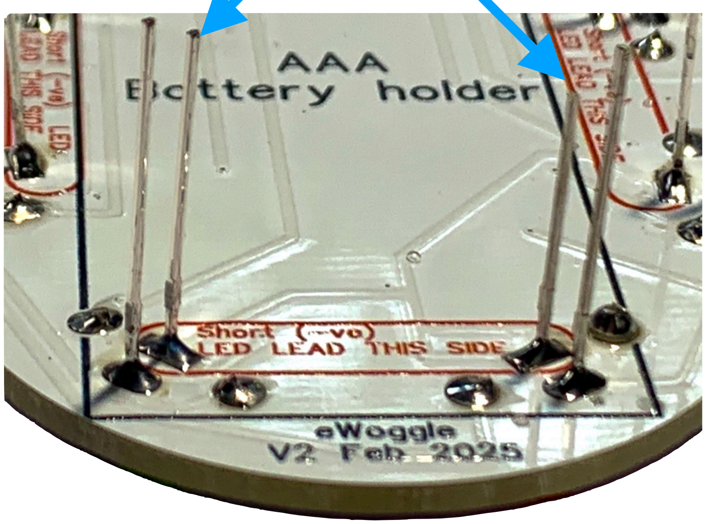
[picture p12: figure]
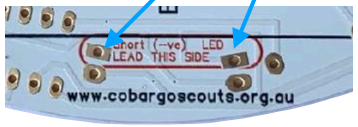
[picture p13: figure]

1st Cobargo Scouts | Page 1 | V1 - Mar 2025

Please turn over the page for the rest of the installation instructions.

Leave the instructions on the table , do not take them with you.

Red numbers represent the order in which the components should be installed.

1,2,3 and 4
Yellow-Purple-Brown-Gold

5
Brown-Black-Orange-Gold

Put the 8 coloured LED’s in from the front of the board, note that the colours must be in the same locations as the above photo
Note - The Flat side with the short lead is the “-“ lead and goes in the hole towards the middle of the board.
Get a leader to look at them before you solder them in.
They will not work if you put them in the wrong way round.

7-14 LED’s 1-8

6
Note the Notch at one end of the socket, must line up with the notch on the board

look at the back of the board, the short lead goes in the holes towards the middle of the board (outlined in red)

# eWoggle assembly instructions

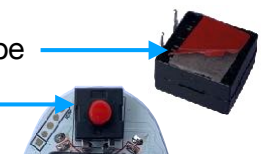
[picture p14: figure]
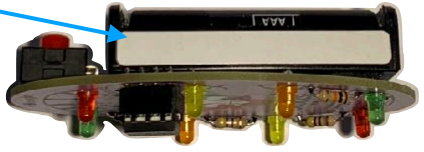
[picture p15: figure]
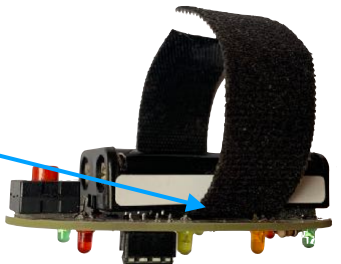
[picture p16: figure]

1st Cobargo Scouts | Page 2 | V1 - Mar 2025

Leave the instructions on the table , do not take them with you.

## 15 Remove the Red top layer of the double sided tape Solder the switch onto the back of the board

## The Switch and battery Holder are installed on the

rear of the Board,

### Ask your leader for the battery holder, batteries and IC. They will test

your board 1st before you solder in the battery holder in.

## 16 Remove the red top layer of the double sided tape Solder the battery holder into the back of the board

## 17 Write your name and group on the label onto side of the battery holder

## 18 Slide the Velcro between the battery and the board

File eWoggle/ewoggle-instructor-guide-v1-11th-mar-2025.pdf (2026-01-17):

# eWoggle Instructor Guide

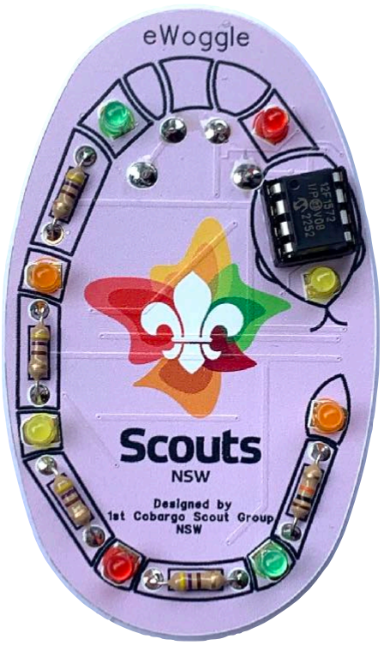
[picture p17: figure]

www.cobargoscouts.org.au | V1 - Mar 2025 | Page 1

Please read these instructions fully, and take particular note on ordering the PCB and checking the order. This kit has been made with EASYEDA Pro, and is using a Multicolour Silkscreen board that you order from JLCPCB. So please follow the ordering instructions carefully, (page 6 and 7) otherwise you will end up

with a board with no Scouts Logo.

## NOTE: This kit has been built with AAA Batteries, it only weighs about 42g. It is not heavy when attached to a standard rolled

Scout Scarf.

## Please do not redesign it with a button cell Lithium battery, as

these are not safe to use with youth members.

## Design principles

The eWoggle is designed to be built by young Scouting youth members with limited to no soldering experience. It has many design principles that should ensure lower assembly failure rate, and a longer lasting robust kit.

Design features
- Low profile on/off switch, partially shielded by the battery holder - to reduce the ability to be accidentally turned on, when squashed up against other things in a bag.
- PCB Mount battery holder, that wont break off.
- Larger solder pads 2.5-3mm, to make soldering easier for Scouts
- Wide spacing for radial component leads to prevent solder bridges, and components laid down to prevent breakage.
- Wider tracks so that if through holes are delaminated, then the component lead can be soldered to the track - saves replacing the board and starting again,
- No more than 1 track connected to a through hole to reduce the number of tracks to be reconnected if a pad is delaminated.
- Step by step assembly process, with stops to ensure faults are captured early enough to prevent issues that require rework.

### Design notes

- The eWoggle has been designed to be used as a woggle on a Scout Scarf. It has double sided Velcro that is fed between the battery holder and PCB, that holds it securely onto a Scout scarf.
- AAA batteries have been used in this project. A lithium ion battery was not used for safety purposes. By law, any lithium ion battery powered project requires a case with a captive screw to stop young children ingesting them. There are no PCB mount battery holders on the market with captive screws, available, so for safety reasons AAA batteries were used. Please do not modify this project to use a lithium ion battery.
- When the board is attached to a Scarf with Velcro, the Velcro pulls the scarf round the side of the battery holder, and effectively hides it. So the size of the AAA batteries are not an issue..
- The combined thickness of the battery holder and PCB is less than the thickness of the average woggle.
- The weight of the eWoggle with batteries is about 42 grams ( 3 times the weight of my Gillwell woggle), and the weight is not noticeable when attached to the average rolled Scout scarf worn round the neck.

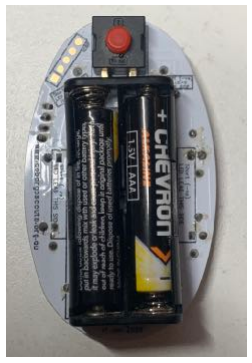
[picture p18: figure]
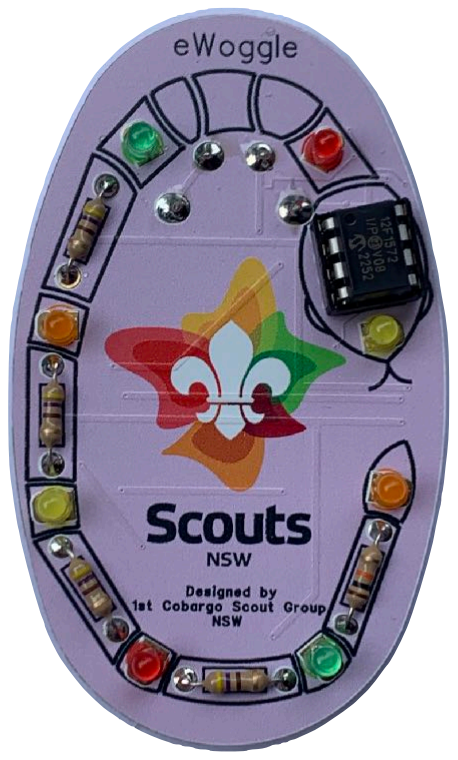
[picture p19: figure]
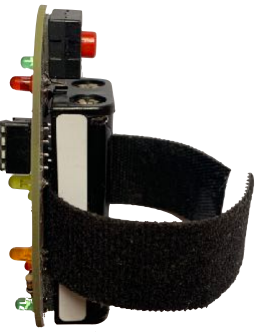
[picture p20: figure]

## Circuit details

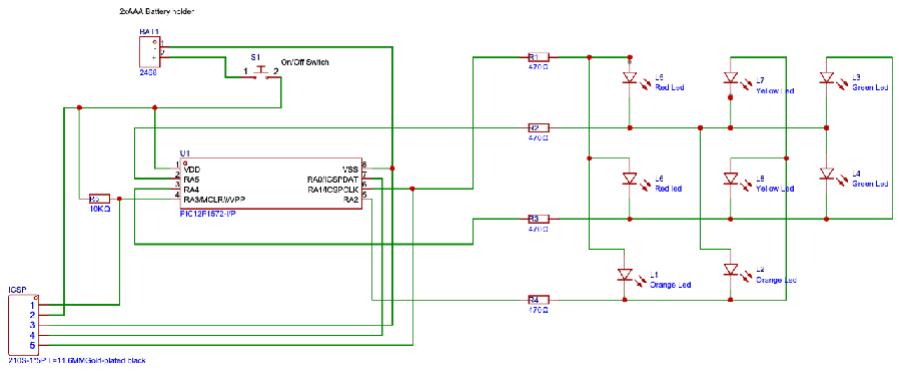
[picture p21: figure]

This project is based on a PIC12F1572 microcontroller. It generates 7 different patterns on the 8 LED’s, in a roughly 2 minute cycle.

Only 1 LED is actually on at a time, as the LEDS’s are arranged in a “Charlieplexing arrangement. The circuit draws about 2-3ma, and works down to about 2.6v, so it should (but not tested) run in excess of 100 hours if you put in a good quality AAA batteries.

Its has a set of ICSP pads on the board, but as it does not have a blocking diode(to reduce component count) between MCLR and VDD, its recommended that you do not use ICSP if the batteries are installed, so take them out first, or program the PIC’s before putting them in.

## Pic programming options

You will need a PIC programmer

The following programmer and ZIF socket does the job nicely, just get the PicKit 3.5 with ICD2

https://www.aliexpress.com/item/4001283158851.html?spm=a2g0o.order_list.order_list_main.25.10f01802ENwKsh (https://www.aliexpress.com/item/4001283158851.html)

Note MPLAB version 6.2 supports this programmer, higher versions no longer support PicKit 2,3 or 3.5

## Source Code

The code is available for download on the same page you found this documentation.
It is available in 2 formats -
1) Complied Hex file ready to program the Pic using MPLAB IPE.
2) C file in HTML form
3) Source main.c file, in case you want to play with the program and make it better. If you do play with it and add extra patterns etc, then please send me a copy and I will publish it on the Cobargo Website with your name on it. Please send both the main.c file and Hex File
Email to michael.Gross@nsw.scouts.com.au or venturers@cobargoscouts.org.au

Disclaimer - I am not an expert programmer - i am self taught using Google searches, and much hair pulling (only kidding), so don’t groan too much at my code - it works but its not pretty !!!!

## Programming methods

There are 2 methods you can use to program the PIC

1) Program them beforehand in a pic programmer, So that they just need to be put into the IC socket, once the Scouts have soldered it together - This is by far the easiest Option.
2) Program the Pic using ICSP, once the Scouts have soldered it together.

WARNING - This option is a lot more involved and I have only included it for those that like to do ICSP, and just because I could add it in - call it over the top design - i just could not help myself !!! If you have designed PIC boards before you will understand/sympathise - LOL !!!!

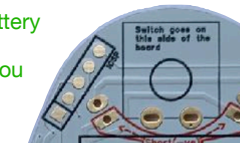
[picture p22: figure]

The Board has ICSP contacts on it. You would need to ensure that the Battery
holder is not soldered in until the PIC has been programmed and Board
tested using this method as a blank PIC will not illuminate any LED’s, so you will not know if there are any assembly issues, and the battery holder is
hard to remove once soldered on as the double sided tape is rather
strong.

Also its important not to have batteries installed when you program the PIC as there is no blocking diode - to reduce component count and cost.

To program the PIC using ICSP, you will need one of the following - get a 5 pin Single row 2.54mm spacing

https://www.aliexpress.com/item/1005006358713448.html?spm=a2g0o.order_list.order_list_main.57.50371802Un3mEP (https://www.aliexpress.com/item/1005006358713448.html)

## Connecting to the ICSP Pins

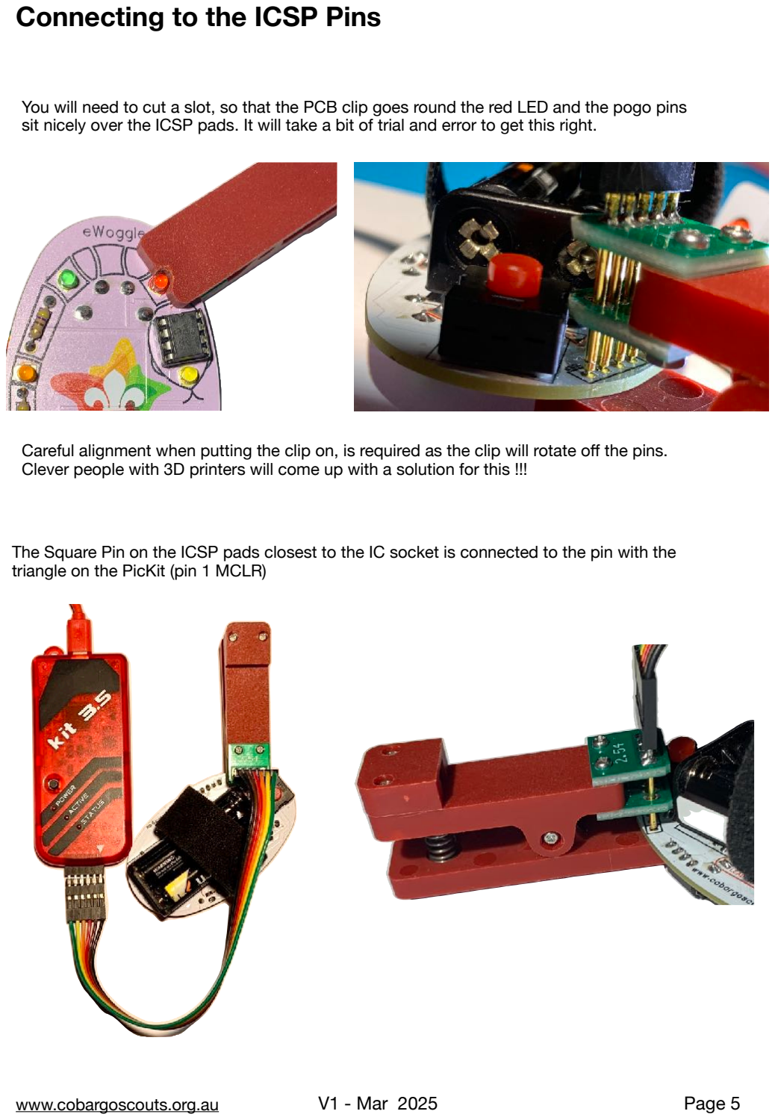
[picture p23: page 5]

You will need to cut a slot, so that the PCB clip goes round the red LED and the pogo pins sit nicely over the ICSP pads. It will take a bit of trial and error to get this right.

Careful alignment when putting the clip on, is required as the clip will rotate off the pins. Clever people with 3D printers will come up with a solution for this !!!

The Square Pin on the ICSP pads closest to the IC socket is connected to the pin with the triangle on the PicKit (pin 1 MCLR)

## Ordering the PCB

### Please also read the next page on Checking the Order on JLCPCB

The PCB has a multicolour Silkscreen on both Sides. The top side has the Scout Logo in colour, and the bottom side had a red outline denoting where the “-ve” LED leads go.
It has been designed with EASYEDA PRO. https://pro.easyeda.com/ The Pro version is free, and is the only version that supports the muticolour Silkscreen, so you must use it otherwise the Scout logo etc will be missing on the boards.

Also you will need to get the boards printed at JLCPCB, as the Gerber export with a multicolour silkscreen will work with JLCPCB, but i am not sure if it will work with other PCB manufacturers.

As usual I have provided the original design files, so that you can change logos and wording to suit your particular state/group

*** Attribution ***
Please note: these designs are provide free for Scouts to use, the only thing we ask is that you leave all references to Cobargo Scouts on the PCB’s. Small price to pay for the free designs.

The 2 references are
1- "Designed by Cobargo Scouts", and
2- Our web address “www.cobargoscouts.org.au"

READ CAREFULLY - Very important otherwise you will not get the logo on the board.

1) Once you have created an account on EASYEDA Pro, and uploaded the design files you will need to configure EASYEDA Pro to tell it that you are using Multicolour Silkscreens. Look at the following document. https://prodocs.easyeda.com/en/pcb/other-draw-colorful-silkscreen/
2) It describes how to configure EASYEDA pro to turn on Multicolour Silkscreen, and pay particular attention to the section on “Exporting manufacturing files”, so that the extra 2 silkscreen files are exported with the Gerber to JLCPCB, otherwise you will lose the Silkscreen.
3) Also carefully read the section on “Order Colorful Silkscreen PCB”, as you have to select the correct Base material PCB colour, Surface finish, gold thickness, advanced options etc etc.

NOTE: In Small quantities these boards are more expensive as they are gold plated and use ENIG (google it), in large quantities, they are quite cheap.

## Checking the order on JLCPCB before paying

When you upload the Multicolour Silkscreen Gerber to JLCPCB, you will not see the colour silkscreen on any of the order/cart/checkout pages, don’t panic, if you clicked all the correct options it will be there. Its only visible in a Gerber Viewer window.

Missing the Scout Logo

Shopping Cart View,

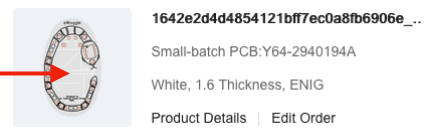
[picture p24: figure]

Once you have put it in the shopping cart, click on the board image and it will open in a Gerber Viewer. If you have done everything correctly, this will have the colour Scout logo on the front. If you look at the rear of the board, the red outline of the “-ve” LED pads only vaguely shows at this stage. This is ok, if the Scout logo appears on the front then the back will turn out OK

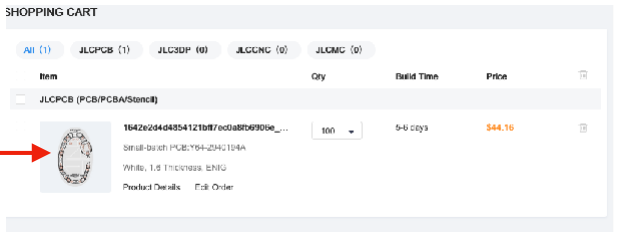
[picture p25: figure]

Click the board image in the shopping cart and it will open a Gerber Viewer window

Shipping cost
Note: there are multiple shipping options when you check out on JLCPCB. Global Standard Direct Line is the cheapest option. The available shipping options are determined by weight. However as a test I added 100 eWoggle boards to a shopping cart, and Global Standard Direct option was available, for $15US.

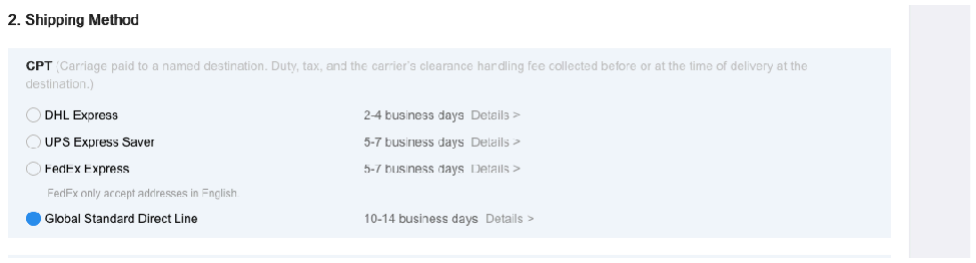
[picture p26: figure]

## Recommended LED’s

Only use, 3mm diffused, red, orange, yellow and green LED’s in this project. They all have a forward voltage in the range of 1.8 - 2V. The circuit will not power, Blue, White, purple etc LED’s that require more voltage. These generally require at least 3.2 V and this circuit will not provide enough power to run them.

## Battery Holder

### Name label

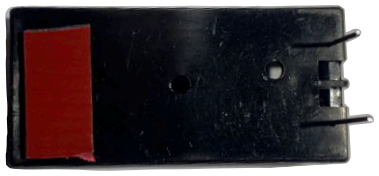
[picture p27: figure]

As the board is small, there is no room to put a white space to write the youth members name and group on. So order the following Avery label and stick it on the side of the battery holder so that they can write their name and group name on it.
https://www.averyproducts.com.au/product/white-rectangle-stickers-932009

The board is designed to do take a PCB mounted AAA battery holder. You will need to put a pice of 2mm thick VHB tape on the end of the battery holder. This is to ensure that it is held securely against the board not only by the pins, but also by the tape. The Velcro used to hold it against the scarf goes between the board and the battery holder, so its important that the battery holder is securely attached to the board by the pins and the tape.
Tape required
3MVHB 4991 (2.3mm Thick) 10-12 mm wide - you will need 1*20mm lengths per battery holder.
can get 3M lengths from aliexpress

(Or any equivalent double sided tape approx 2mm thick)

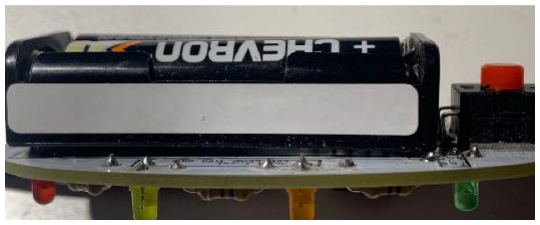
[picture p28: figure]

## Switches

The main ones I have designed the board for, are made by HENGQI https://www.hqdz123.com/en/ and are available on Aliexpress and Amazon, they are all 12mm switches with 90 degree pins.

Option 1 - 1212-112DB

Search for 1212-112DB on Aliexpress
2 pin on/off switch
This is the preferred switch as the pins are longer and more robust than the other switch
They need 0.8mm tape, see below

Tape required for the Switch

These switches only have pins on one side, so if they get knocked they may lift up. Ideally a piece of 3M VHB tape under them will help prevent this. Note 3M VHB tapes can take up to 72 hours to achieve full bonding strength, so it is advisable to stick this to the bottom of the switch a few days before they are due to be assembled by the Scouts.

- Use 0.8mm tape
- 3M VHB 5608 tape (0.8mm thick) 10-12mm wide

https://www.aliexpress.com/item/1005007389297919.html?spm=a2g0o.order_list.order_list_main.5.488b18026RcnLF (https://www.aliexpress.com/item/1005007389297919.html)

## To Do list before the Day

1) Order Boards
2) Order Components
3) Source and buy the 2- Double sided tapes,
4) Put a piece of double sided tape on the battery holder

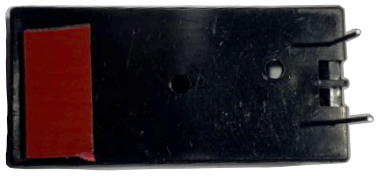
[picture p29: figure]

5) Put the name label on the side of the battery holder.

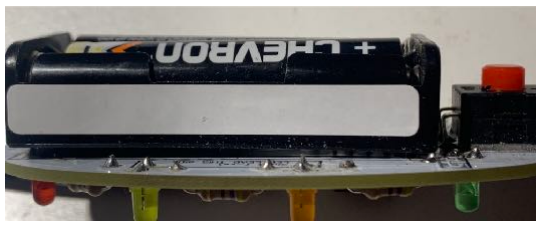
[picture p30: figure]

6) Put the double sided tape onto the back of the switch
7) Solder requirements - Cut 30cm solder (approx 1.3g) for each kit
(Can do it with about 20cm, if you are good at soldering)
8) Download the PIC eWoggle code from the Cobargo website and program and test the IC’s so that they are ready to be put into the boards
9) Print one copy of the Component Sorter per Soldering station, and laminate them. These are used by the Scouts to sort the components, do not let them start soldering until you have checked that they have sorted them correctly
10) Print one copy of the Assembly guide per Soldering station per - it is recommended that you laminate them.

11) Package only the following components
- 5 * Resistors (4 *470 ohm, and 1* 10k ohm)
- 1- 8- pin IC Socket
- 1 * switch
- 8 * Leds - (2 of each colour)
- PCB
- Solder
- Velcro strip
- Do not give out the battery holder, batteries or IC. When the youth members are assembling them, get the Youth to assemble all the components listed above that they have been given 1st (see assembly guide).
- Check the board for soldering issues, dry joints, joined pins, insufficient solder etc.
- Then if all is ok, put in the IC and test the board by putting the batteries in the battery holder and just putting it into the board and twisting is slightly so that it contacts the battery socket pads, and check that it works. Also check that the switch turns off and on alternately. Once you have checked it then let them solder in the battery holder, feed through the Velcro Strip. and then get them to put their name on the label on the side of the battery holder.

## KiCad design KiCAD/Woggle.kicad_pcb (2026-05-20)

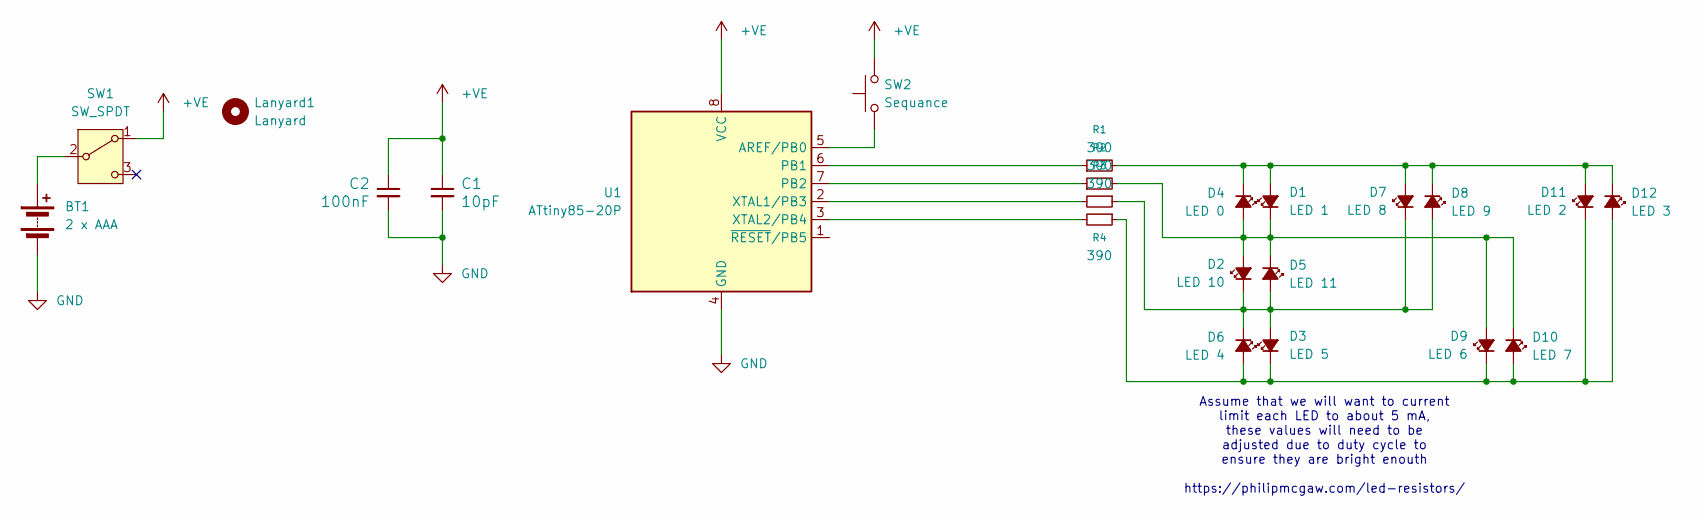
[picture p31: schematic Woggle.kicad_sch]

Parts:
BT1: 2 x AAA; Scouts - 2 x AAA battery cell holder
C1: 10pF; C_Disc_D4.7mm_W2.5mm_P5.00mm
C2: 100nF; C_Disc_D4.7mm_W2.5mm_P5.00mm
D1: LED 1; Scouts - 5mm LED
D2: LED 10; Scouts - 5mm LED
D3: LED 5; Scouts - 5mm LED
D4: LED 0; Scouts - 5mm LED
D5: LED 11; Scouts - 5mm LED
D6: LED 4; Scouts - 5mm LED
D7: LED 8; Scouts - 5mm LED
D8: LED 9; Scouts - 5mm LED
D9: LED 6; Scouts - 5mm LED
D10: LED 7; Scouts - 5mm LED
D11: LED 2; Scouts - 5mm LED
D12: LED 3; Scouts - 5mm LED
Lanyard1: Lanyard; MountingHole_5mm
R1, R2, R3, R4: 390; Scouts - Resistor (10.16mm)
SW1: SW_SPDT; SW_Slide_SPDT_Angled_CK_OS102011MA1Q
SW2: Sequance; SW_PUSH-12mm
U1: ATtiny85-20P; Scouts - DIP 8

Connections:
+VE: C1.1, C2.1, SW1.1 (A), SW2.2, U1.8 (VCC)
GND: BT1.2 (-), C1.2, C2.2, U1.4 (GND)
unnamed: BT1.1 (+), SW1.2 (B)
unnamed: D1.2 (A), D4.1 (K), D7.2 (A), D8.1 (K), D11.2 (A), D12.1 (K), R1.2
unnamed: D1.1 (K), D2.2 (A), D4.2 (A), D5.1 (K), D9.2 (A), D10.1 (K), R2.2
unnamed: D2.1 (K), D3.2 (A), D5.2 (A), D6.1 (K), D7.1 (K), D8.2 (A), R3.1
unnamed: D3.1 (K), D6.2 (A), D9.1 (K), D10.2 (A), D11.1 (K), D12.2 (A), R4.1
unnamed: SW2.1, U1.5 (AREF/PB0)
unnamed: R1.1, U1.6 (PB1)
unnamed: R2.1, U1.7 (PB2)
unnamed: R3.2, U1.2 (XTAL1/PB3)
unnamed: R4.2, U1.3 (XTAL2/PB4)

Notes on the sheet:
Assume that we will want to current limit each LED to about 5 mA, these values will need to be adjusted due to duty cycle to ensure they are bright enouth https://philipmcgaw.com/led-resistors/

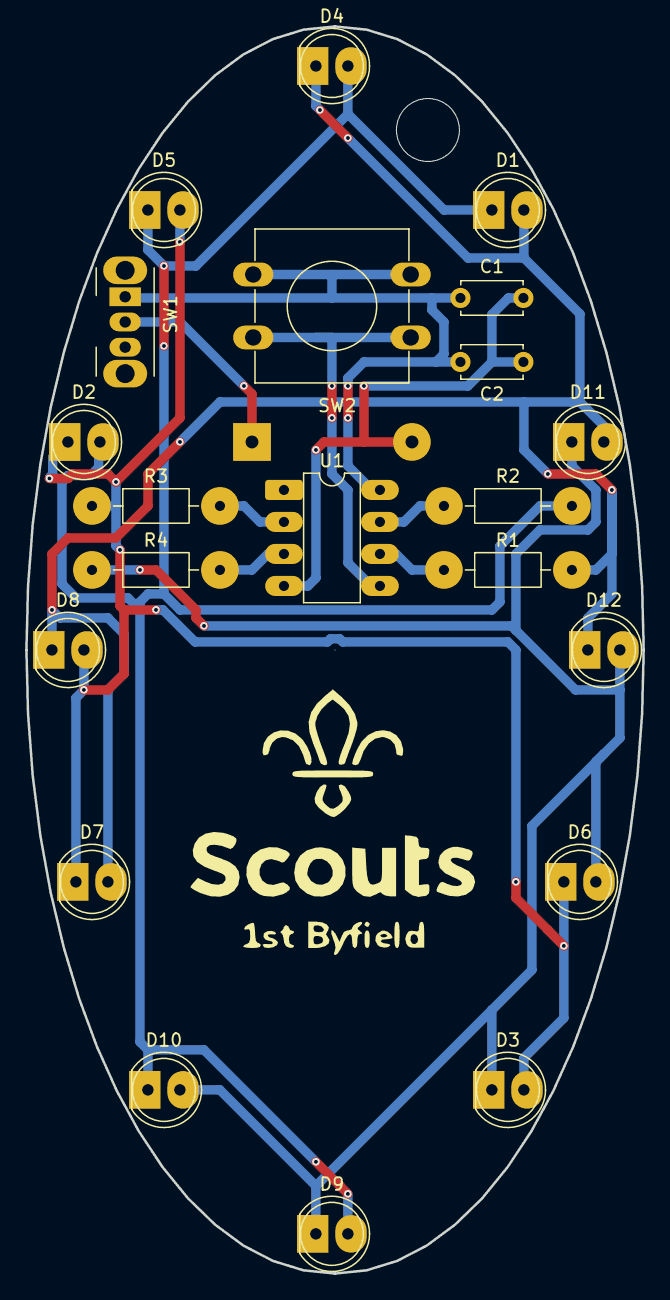
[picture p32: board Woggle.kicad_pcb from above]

Board: 2 copper layers, 49.0 x 99.0 mm, 23 parts (1 on the bottom side), 12 nets.

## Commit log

2026-07-24 Rename folder
    [LED - CXA1304.step, PCB Outline.dxf, PGA2350.step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]
2026-07-24 Removed Common
    [LED - CXA1304.step, PGA2350.step, PGA2350.xlsx]
2026-11-05 Add soldering and welding quiz
2026-11-05 Add soldering workspace safety guidance
2026-11-05 Add beginner soldering hand tools guide
2026-11-05 Add soldering iron selection guidance
2026-11-05 Add soldering accessory guidance
2026-11-05 Add soldering workholding guidance
2026-11-05 Add soldering safety quiz
2026-11-05 Add beginner solder wire guidance
2026-11-05 Add soldering iron setup guidance
2026-11-05 Add guidance for joining wires
2026-11-05 Make soldering timer optional
2026-11-05 Explain magnetic soldering holders
2026-11-05 Add Celsius soldering temperature example
2026-11-05 Record personal iron temperature
2026-11-05 Add component wire soldering guide
2026-11-05 Note preference for stranded wire
2026-11-05 Add wire pre-tinning step
2026-11-05 Add wire soldering illustration TODO
2026-11-05 Add wire splice quiz question
2026-11-05 Add soldering temperature quiz question
2026-11-05 Add LED soldering guide
2026-11-05 Link PanaVise Jr as PCB holder example
2026-11-05 Add magnetic PCB vice build task
2026-11-05 Add resistor soldering guide
2026-11-05 Add capacitor soldering guide
2026-11-05 Add PCB practice board guidance
2026-11-05 Note KiCad in PCB practice guidance
2026-11-05 Explain EAGLE imports in KiCad
2026-11-05 Add PCBWay as my PCB supplier
2026-11-05 Explain ordering boards and matching parts
2026-11-05 Recommend PCBWay from personal use
2026-11-05 Track KiCad woggle PCB setup section
2026-11-05 Add KiCad component list guidance
2026-11-05 Explain how to read PCB markings
2026-11-05 Track PCB silkscreen blog post
2026-11-05 Focus silkscreen blog on diodes and ICs
2026-11-05 Add multi-pin IC socket soldering steps
2026-11-05 Add first-pin reflow step for IC sockets
2026-11-05 Track WordPress blog access follow-up
2026-11-05 Add guidance for soldering large connector lugs
2026-11-05 Introduce the supplied Woggle practice PCB
2026-11-05 Add safe PCB flux-cleaning guidance
2026-11-05 Add solder joint trimming quiz question
2026-11-05 Add lead-bending soldering quiz question
2026-11-05 Add PCB polarity quiz question
2026-11-05 Add KiCad BOM quiz question
2026-11-05 Add open-source PCB files quiz question
2026-11-05 Add upright resistor quiz question
2026-11-05 Add heavy-lug heat quiz question
2026-11-05 Complete nine-question PCB practice quiz
2026-11-05 Add surface-mount soldering preparation
2026-11-05 Include hot plate in SMD further reading
2026-11-05 Add personal SMD hand-soldering range
2026-11-05 Add SOIC hand-soldering preference
2026-11-05 Recommend flux pen for hand-soldered SMDs
2026-11-05 Add hand-soldered SMD methods to annex
2026-11-05 Prefer pin-by-pin SMD soldering
2026-11-05 Add solder paste stencil guidance
2026-11-05 Track SMD blog post updates
2026-11-05 Add SMD solder size quiz question
2026-11-05 Add SMD board cleaning quiz question
2026-11-05 Add solder paste storage quiz question
2026-11-05 Explain fixing excess through-hole solder
2026-11-05 Explain correcting insufficient through-hole solder
2026-11-05 Explain fixing a cold solder joint
2026-11-05 Explain fixing a disturbed solder joint
2026-11-05 Explain removing a through-hole component
2026-11-05 Explain fixing excess solder on SMD joints
2026-11-05 Explain removing a surface-mount IC
2026-11-06 Add advanced PCB track repair guidance
2026-11-06 Move PCB track repair to blog TODO
2026-11-06 Record PCB track repair method for blog
2026-11-06 Record jumper wire securing method
2026-11-06 Add solder joint quality quiz question
2026-11-06 Add PCB repair quiz note to blog TODO
2026-11-06 Add disturbed joint quiz note to blog TODO
2026-11-06 Add cold joint quiz note to repair blog
2026-11-06 Add solder bridge quiz note to repair blog
2026-11-06 Add next steps after soldering
2026-11-06 Use IEC symbols in Scouts schematic notes
2026-11-06 Link resistor colour wheel in leaders guide
2026-11-06 List IET Scout booklet circuit projects
2026-11-06 Review Basic Electronics source material
2026-11-06 Link LED resistor article in draft
2026-11-06 Add battery and sensor blog outlines
2026-11-06 Fold sensor divider into resistor article plan
2026-11-06 Use thermistor in resistor article outline
2026-11-06 Track fundamentals course exercise files
2026-11-06 Explain electrical charge for Scouts
2026-11-06 Add Kitronik soldering starter kit
2026-11-06 Recommend Kitronik solder wick
2026-11-06 Add Kitronik soldering starter kit option
2026-11-06 Explain voltage as potential difference
2026-11-06 Explain current in a complete circuit
2026-11-06 Use conventional current direction throughout
2026-11-06 Explain basic circuit paths and faults
2026-11-06 Track capacitor prefix article corrections
2026-11-06 Record resistor article review notes
2026-11-06 Link Ohm and power articles in drafts
2026-11-06 Clarify LED current limiting
2026-11-06 Add LED current limit calculation example
2026-11-06 Review LED current challenge sheet
2026-11-06 Explain LED resistor calculation method
2026-11-06 Review LED resistor values article
2026-11-06 Add voltage question to fundamentals quiz
2026-11-06 Add electron flow quiz question
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2026-11-06 Explain what a blown meter fuse means
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2026-11-06 Correct battery challenge heading
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2026-11-11 Add fixed-value resistor knowledge check
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2026-11-11 Add resistor tolerance knowledge check
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2026-11-11 Record voltage divider diagram correction
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2026-11-12 Document the RC and RL filter quiz answer
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
